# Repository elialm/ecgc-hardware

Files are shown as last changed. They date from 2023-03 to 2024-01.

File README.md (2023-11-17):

# ecgc-hardware

This repo contains all relevant documentation of the cartridge hardware.

The `legacy` directory contains legacy documentation.
This is just a collection of documents I made *waaaay* back when I was
just starting on the project.
It is included here just as an archive so I don't plan on updating anything.

The `CartGen3ProtoBoard` directory contains the schematics for the
first working prototype mentioned at [my website](https://efacdev.nl/posts/ecgc/20220601).
The photograph below is this prototype.

[gen3prototype-photo](https://user-images.githubusercontent.com/43206514/217519505-81669f43-df62-44b2-97f7-6338e39c4504.png)

The `CartGen4` directory contains the schematics for the
next prototype.
I've included some renders of it below.

[gen4-render-front](/CartGen4/img/front.png)  
[gen4-render-back](/CartGen4/img/back.png)

# Development tools

The tools used to make the schematics is [KiCad](https://www.kicad.org/).
It can be used to open the `*.kicad_pro` file to open the schematic
project.

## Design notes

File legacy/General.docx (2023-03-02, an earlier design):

# Gameboy flash cartridge

# Foreword

This document is a general overlook on the project. Here I explain mostly how my thought process went and which steps I took to get to where I am now. Additional references are provided to those who are interested in helping/making something cool which my sources (I’d love to see someone taking my work and expanding on it).

For a bit of context: I’m a HBO student (sort of University, but not quite) in the Netherlands studying ICT & Technology. During my study, I learned to program (C#, C and C++) and also learned how to work with microcontrollers and the like (among other things). I love working with low level stuff and am enthusiastic about learning about all kinds of different technologies.

During the Corona pandemic, I was looking for a way to fill my time. A year prior, I stumbled on the documentation for the GB. As I’m quite curious about older hardware and wanted to study more about the inner workings of computers/processors, I was quite interested in developing something for the GB. I didn’t really want to make a game (I’m not a game developer) and I didn’t have any other idea (or time) to use this information, so I quickly canned it.

After I bought a used GBC on ‘Marktplaats’ (basically eBay in the Netherlands), I was looking for ways to use it. I wanted to experience the hardware first-hand by playing some games on it and upgrade the thing to be a bit more modern (Li-ion battery mod and IPS screen mod), I saw a flashcard for it. As I was looking at it, I started to think about how that darn thing works, which led me to the path of trying to make one. I also had quite some free time during the pandemic, so that helped seal the deal.

# Description

The project goal, is to develop a flash cartridge for GB/GBC like the one in the picture below. The flash cartridge should be able to load games from a library on a common storage medium (best candidate is SD card) to play on the handheld. I want the cart to be compatible with GB and GBC (I may think about the GBS, but that is currently not the focus).

The project is separated into 3 parts: the cart hardware, the cart firmware and a selection menu software. I will need a game cart, capable of accommodating an SD card and additionally needed hardware (RTC and possibly more). I will also need some firmware to load the game, communicate with the SD card and probably some other stuff. And I will need a way for a user to select a game from the flash card for the cart to load.

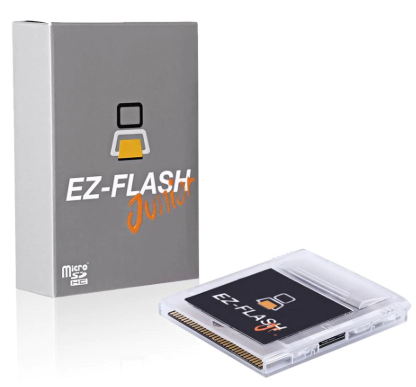
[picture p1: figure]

A picture of the EZ-FLASH GB flash card. Source: https://pt.aliexpress.com/item/4000718442858.html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

I currently have no real experience in developing hardware, so I will probably make a lot of mistakes in the electrical part (I’m a Software Engineer in training). My plan is to research the GB hardware to get an idea of what I need, then make a prototype cart, in order to test some firmware on it and get a better idea of what I need. Then, I’ll basically repeat this procedure, till I get the result I want.

# Requirements

As stated in Description, the ultimate goal is to create a cart that can load games from an SD card. For development, I need to break the project down into smaller parts.

## User requirements

1. As a user, I must be able to select a GB game file on the SD card, in order for me to play it. This is the basic requirement I need the cart to do. When a user insert the cart and boots the handheld, it should boot to a game selection menu of sorts, where a user can select his/her game.  In order to do this, I will need to be able to communicate with the cart to firstly get the game list, then by the user’s selection, load said game into some sort of buffer, as the GB can’t read directly from the SD card (refer to Research document ‘Bus decoding’ as to why). While the cart is responsible for loading games, I will also need a user interface to run on the GB. This will be the first thing that the GB loads when booting from the cart.
2. As a developer, I want to be able to write my own firmware versions, in order to add functionality to the cart As I’m a curious soul and want to spread that to the masses, I want to share the knowledge acquired from the project and document everything important for other people to develop their own firmware version (or maybe their own cart).  I will share documentation and other files regarding the development of this cart and publish it somewhere on the internet.
3. As a user, I want to be able to relatively easy change the look of the user interface, in order to customise my experience I like to customise my menu’s (be it my desktop, phone or 3DS). I want to add the functionality to change the look of the game selection menu (fonts, splash screen, BGM, you name it).  It’s a lower priority, but I will try to make a desktop program to make a ‘theme’ file, which you can put on the SD card to change the look of the UI.
4. As a user, I want to be able to create backups of my save files, in order not to lose progress. As someone who enjoys games, I despise it when I lose my saves. Now it’s becoming harder to lose said saves, with cloud storage and all (thank god), so I want to take that modern approach and use it on my platform.  It will probably take quite some work and it’s not really important, but it would be nice to have some kind of service that the cart can connect to, in order to backup saves (some kind of OneDrive). It would be cool if the cart has Wi-Fi hardware, so that it could communicate with such a service.
5. As a user, I want to be able to play multiplayer games that I would normally play using the Link interface or IR interface, but then over Wi-Fi, in order to play with people all over the world. Quite ambitious, but it is a cool idea. If I could figure out how to hijack the Link or IR interfaces, I could reroute the data from those interfaces through a network socket. Theoretically, one could then connect with users al over the globe and play multiplayer.  As this a HUGE requirement, it will receive a low priority. In order to do this, I would probably make some kind of service that clients can use to connect to one another. Same as the backup requirement, it takes a lot of time and effort to create such a think and it’s something to do, when the cart itself doesn’t have anything else going on.

## Functional requirements

Based on the user requirements and some research, I formulated these requirements. These requirements describe the more detailed requirements on a system level, needed to fulfil the user requirements.

1. The GB and cart must be able to communicate with each other To instigate certain behaviours in and to pass data to both the GB and cart (think about the cart telling the GB which games are available or the GB telling the cart which game it has selected), the GB and cart will need to be able to communicate with each other.  As the interface in between the GB and cart is the address and data lines, the cart will need to use a bit of the address space as a communication medium. I will probably use a bit of the cart RAM, but I will think about it when the time comes.
2. The cart needs to communicate with the SD card To read games and save data to non-volatile storage, the cart will need to communicate with the SD card.  Communicating with an SD card goes over an SPI connection. The cart will then need SPI functionality. For the software part, I will probably use some open source library. Writing it myself seems unnecessary. Although, it might be a fun learning experience.
3. The cart will need some ‘brains’ to execute certain commands To do stuff like communicate with the SD card and GB, read and write data, the cart is going to need some central processing. Also for me to customise the behaviour of the cart and because it needs to do some complex stuff, it seems wise to do this software based.  I will probably slap a microcontroller on the cart to do these things. Additionally, the research till now, suggests I will need some hardware acceleration, so an FPGA might also be handy. I’ve never used one before, but I’ve been wanting to learn to develop for an FPGA, so again, an excuse to do something new! I currently looking into something called PSoC.
4. The cart will need a memory buffer to act as cart ROM and RAM The GB uses a parallel 16-bit address and 8-bit data bus to communicate with what normally is the ROM (and RAM) on the cart. As the speed with which the GB reads from and writes to the cart is quite fast, it would be wise to have a buffer in between the data on the SD card and the GB. This would ensure both speed and minimise wear on the flash medium.  I will probably use some RAM chips to act as the memory buffer. It’s fast, reliable and resistant to the wear and tear from every game load.
5. The cart will need an RTC unit Some games on the GB use an RTC. This is a piece of hardware, which can keep track of the date and time. This is also a convenient thing to have, for the purpose of displaying time.  The easiest thing to have, is a MCU that has an integrated RTC. This is a common thing, so it shouldn’t be hard to find one.

## Non-functional requirements

1. Cart should use least power possible Because the GB is known for being low power, I want my cartridge to use the least amount of power possible. Use of the cartridge shouldn’t drain 2 AA batteries in an abnormal way.  This should be achieved by carefully writing the cart firmware and disabling any peripherals not needed at the moment. I could also choose low power chips inside the cart.

# General idea

Here I describe the general idea of how I want to design my system. This includes all parts of my system and how they communicate/interact with each other. This will be quite rough, but should serve as a strong base to build upon.

## Cartridge hardware

The cart can be separated into 3 main parts: the Bus decoder, the memory and the MCU (Microcontroller). See below for an image visualising the connections between the parts.

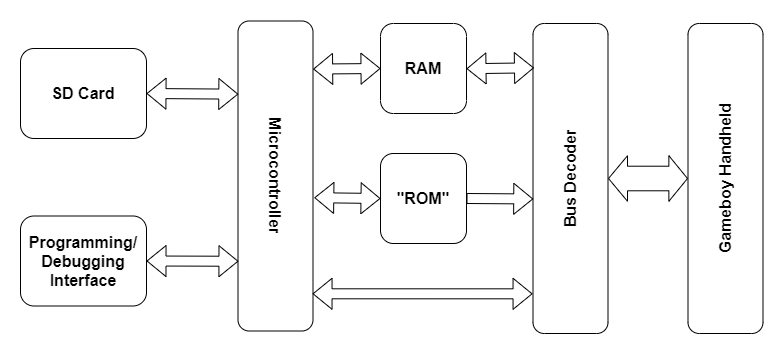
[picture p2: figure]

Diagram showing the different parts of the cartridge and how they can interact.

The Bus decoder is the part which communicates with the GB. Its job is to decode the read/write requests from the GB and execute them. For a more detailed explanation about the decoder, see TODO: Write detailed explanation about decoder

The memory is where the game code and data reside. This is made out of 2 parts: the “ROM”, which is the part of the RAM that acts as ROM; and the RAM, which is also RAM and can be used by the GB as cart RAM. For a more detailed explanation about the memory, see TODO: Write detailed explanation about memory

And finally, the MCU. This part runs the firmware code and is responsible for the more complex behaviour of the cart. This part also communicates with the SD card, for loading in game code and data. For a more detailed explanation about the MCU, see TODO: Write detailed explanation about MCU

## Cartridge firmware

The firmware is the code running on the MCU which resides on the cart. To facilitate the execution of certain behaviours, it seemed wise to have a MCU with updateable firmware. The original plan is to have a MCU with a bootloader, which reads a firmware file on the SD card and executes this firmware.

The general stuff the firmware does is as follows:

- When starting up, read and download the firmware file on the SD card (done by the bootloader)
- Upload the menu program for the GB into the cart memory
- Configure the decoder for use with menu program
- Enter in a mode, which waits for requests from the GB (e.g. load selected game, get or set the date/time)
- When a game has been selected, upload selected game (and optionally save data) into the cart memory
- Configure decoder for use with selected game
- Enter power saving mode, if MCU is not needed anymore
- When GB powers off, save the RAM to a file on the SD card

For a more detailed explanation about how the firmware works, refer to the code. I’ve written enough comments to adequality explain the inner workings.

TODO: Write the damn code

## GB User Interface

# Cartridge Iterations

This chapter is to show the different iterations I’ve made of the cartridge and to discuss how they works, why I did certain things and what I would change about them in the next iteration.

## Model PT - Prototype Test

This is the first prototype made for this project. As I’ve wanted to experiment with the memory, I’ve let out the MCU out of this design. I don’t have any experience in designing a board for a MCU and I didn’t want to have complications because of that. Also, I haven’t decided on the MCU that will run the show and I wanted to do this after I have a better picture about using the memory. This iteration also doesn’t have an SD card reader for the same reason. MCU and SD card reader should be added externally.

### Hardware

This design contains 2 RAM chips: a 64Mbit and a 1Mbit chip. The 64Mbit is to be used as the “ROM” section of memory and the 1Mbit chip as the RAM section. Both chips are connected to the address bus coming from the GB to access their part of the memory map (see research document for an explanation why TODO: Write said explanation). Because the chips are much bigger then their allocated part in the memory map, they have a couple extra address lines to address the banked memory. The extra lines are connected to jumper pins, which can be connected to a MCU for the higher addresses (See picture below for diagram showing the address pins wiring). When the GB then wants to access different banks, the higher bits should then be set by the MCU, in order to access these banks.

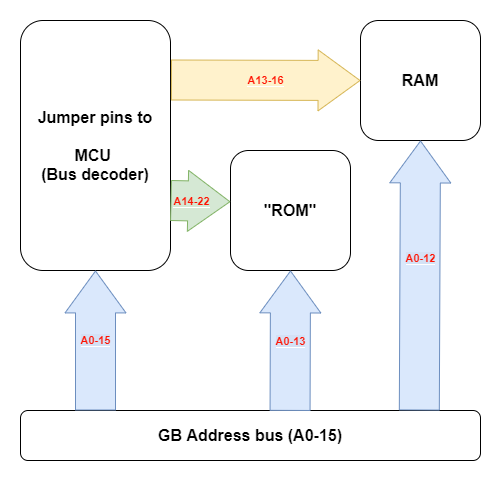
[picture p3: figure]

Image showing wiring of address lines.

Additionally, the data bus of both chips are also connected to each other and to the GB data bus (See image below for wiring diagram). As these lines can be driven by the RAM chips, care should be taken that they don’t try to use the data bus at the same time. This can be achieved by using the ‘Output Enable’ and ‘Chip Enable/Select’ pins of each chip (accessible via the jumper pins). Still, read their datasheets for a more detailed explanation of their inner workings.

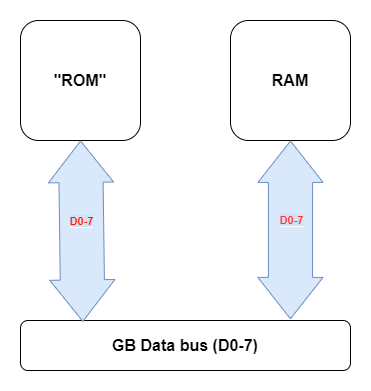
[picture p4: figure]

Image showing wiring for data bus.

I couldn’t find RAM chips of adequate size that work on 5V, So I’ve had to settle on chips that work on 3.3V. Because of this, I needed some components as voltage translators. The most notable are the bus transceivers, which are mainly used as down translators that translate the 5V logic signals coming from the GB to 3.3V signals (address bus, data bus and control signals). They have another function, which is to isolate the GB when the MCU wants to access the RAM chips. During some operations (e.g. when loading in the selected game) the GB shouldn’t be able to access the cart memory, so the bus transceiver can be used to block the GB’s signals. This can be achieved manipulating the control pins of the bus transceivers (see their respected datasheet for how they operate).

Because of the fact the RAM works with 3.3V logic, I’ve made the decision to use only 3.3V logic on the cartridge. This should simplify communication between components on the chip (I don’t have to constantly translate voltages). The only isolation still needed by the cart, is the RESET line. This is a line the cart can pull down to reset the GB. As this is also 5V logic, I’ve isolated it from the rest of the cart, using a level shifter. The level shifter can be used to pull the RESET line down.

To use the cart, I’ve exposed some connections by using jumper pins. These connect to nets, which I’ve seen as useful to have access to. These pins should then be connected to a microcontroller. WARNING: All pins connect to 3.3V logic. You should NOT put 5V on these lines. Doing so will most probably damage components on the board. There are 3 sets of 8 pins. The unlabelled pins are connected to ground. For description on the labelled pins, please refer to the next table.

Pin(s) | Name | Description
DIR | Direction | Change the input/output direction of data transceiver.
OE | Output Enable | Enable the output of data on the 1Mbit RAM chip.
CS | Chip Select | Enable 1Mbit RAM chip.
WE | Write Enable | Specify a read or write operation on the 1Mbit RAM chip.
A13-16 | Address lines | Higher address lines of the 1Mbit RAM chip.
RST | Reset | GB reset line (connected through level shifter). Pull down to reset GB.
CS | Chip Select | GB chip select line (down-translated to 3.3V). Active LOW. When active, GB is communicating with cart.
RD | Read | GB read line (down-translated to 3.3V). Active HIGH (HIGH means read). Is opposite from WR line.
WR | Write | GB write line (down-translated to 3.3V). Active LOW (LOW means write). Is opposite from RD line.
CLK | Clock | GB clock line (down-translated to 3.3V). Used to time read/write operations.
OE | Output Enable | Enable the output of data on the 64Mbit RAM chip. Pull high to tristate the output (for manipulating address lines via MCU).
CE | Chip Enable | Enable 64Mbit RAM chip.
WE | Write Enable | Specify a read or write operation on the 64Mbit RAM chip.
A22-14 | Address lines | Higher address lines of the 64Mbit RAM chip.
A15-0 | Address lines | GB address lines (down-translated to 3.3V)

Some of the pins on the chip have either been pulled high or low, because they weren’t needed to be changed during operation. To identify these pins and see where they are tied to, please refer to the schematics. For more details about how to use these chips, please refer to their respected datasheets. To identify the pins, please refer to the silk screen on the board (or see picture below).

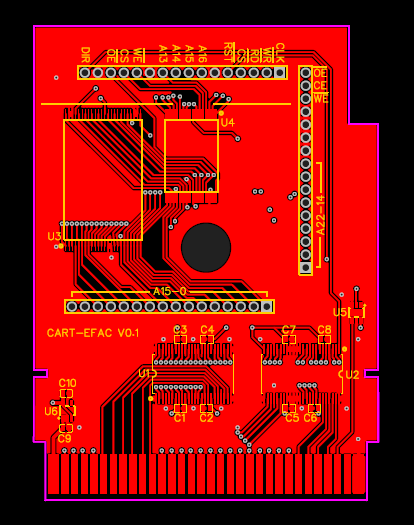
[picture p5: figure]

Image of top of board design, on which the silk screen can be visible.

For more details on wiring, see schematics and/or board design.

### Fixes for next iteration

This board has a lot of faults. The faults are so big and numerous in fact, that I haven’t used this iteration for any testing. When I was inspecting the boards after I’d ordered them my big glowing brain started working again and I found a lot of things wrong with it (like missing pins and wrong connections). Nothing wrong with the company who made the board or the manufacture of the board, just design faults I made (to make things clear). Here’s a list of faults with the board to fix with the next iteration:

RST Buffer doesn’t block 5V
When I designed the board, I wanted to be able to reset the GB via the RESET line. Because this is connected to the GB, it is 5V logic. To protect the MCU running on 3.3V, I put a buffer on the board connected to the RESET line (see U5). I thought this would block the 5V of the pin, but when not connecting the input of the buffer, the input sits at around 5V. When driving the pin to 3.3V (which would mean that the GB shouldn’t reset), it drops down to about 4V.

As this is not ideal, I’ve decided to remove the buffer and replace it with a voltage divider circuit. If I use a 10k and 20k resistor, I should be able to lower the RESET line voltage going to a GPIO pin on the MCU, whilst being able to pull this line down via the resistor (and resetting the GB).

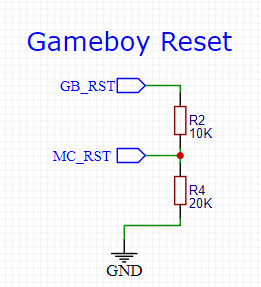
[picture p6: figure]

Image showing current setup for the reset pin

Linear power supply not enabled
I put a linear power supply on the board, in order to power the 3.3V components on the board from the 5V power supply coming from the GB. The chip I chose, had a enable pin, which was active high (the power supply is enabled when connected to HIGH). Because I apparently only had one braincell working, I connected it to the output of the supply. Because of this, you have a classic chicken and egg problem, where the enable line must go HIGH, but to do that, the supply must be enabled. Just wonderful…

The solution is simple, just connect the enable pin to a voltage divider. If I use a 10k and 20k resistor connected to 5V (GB power rail), the supply should drop to about 3V, which the enable pin sees as HIGH (according to the datasheet, it sees voltages higher than 1.2V as HIGH).

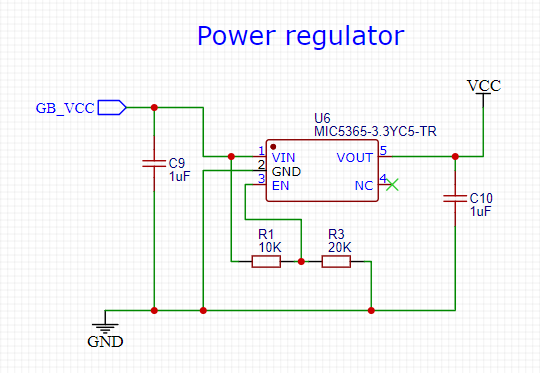
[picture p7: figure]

Image showing current setup for Linear power supply.

Some dimensions are wrong
To get the dimensions of a board that could fit inside a cartridge, I using an empty plastic cartridge and the board inside it. I must have measured things almost perfectly, because the board was a tad to big (like maybe 0.2 bigger in most dimensions). Because of this, I had to sand some sides down to get it to fit.

Also, the thickness of the board it to large. When I tried to put the board inside the plastic casing, the lid wouldn’t close. I eventually got it closed, but then the card wouldn’t slide completely inside the cart slot. The board is to thicc to fit inside the cart slot.

And finally, the hole is a bit higher then it should be. Luckily, the hole was big enough to still fit, but this is not ideal.

I’ll give the next iteration some clearance, so that I don’t have to sand it again (not that it’s terrible, but since I’m making a new one anyway, I might as well change it). And more importantly, I next need to order a thinner PCB. I measured with a random board it to be 0.8 mm. Also, I need to change the size and position of the hole to fit nicely.

Data bus not accessible via pin to MCU
Quite an embarrassing thing to forget, but I forgot to add pins to connect the data bus coming from the bus transceiver to the MCU. Because of this, the MCU can’t put data on the bus to write to memory, meaning it can’t load the game.

As this is pretty important, this should be fixed in the next iteration. I’ll next add some extra pins, which are connected to the data bus.

## Model PM - Prototype Modular

For the next iteration, I wanted to make a drastic change. When buying the parts for the last iteration, I accidentally bought the wrong 64Mbit chips. I originally ordered it from another supplier, because the SRAM chip costs about €26 on Mouser and I found another for about €2,50. The price difference should’ve been obvious, but I don’t think I had slept well that night. So now I have 256kbit chips laying around for other projects.

Because I don’t want to ‘waste’ a €26 chip on every iteration, I decided to make the next iteration modular. I made this one with the possibility to connect 2 daughter boards: one for memory and one for the MCU. This way I can reuse this iteration and when I want to add the MCU, I can just make a daughter board for it. For now, I’ll just make a daughter board with pins to connect to an external MCU (for testing purposes) and a daughter board for the memory (“ROM” and RAM).

### Hardware

Firstly, let’s go over some changes compared to the last iteration:

As stated in the introduction, I’ve made the change to be able to add daughterboards. I’ve opted for a 40 (2 x 20) pin interface with the memory board and a 50 (24 + 26) pin interface with the MCU board. I chose to use 2 connectors to distribute the pins better and to have a more stable physical connection.

The wiring of the address bus is slightly different. In the last iteration, I wired the address buss coming from the GB directly to both memory chips, while 2 separate busses for the higher addresses exist. Because the bus can either be used to communicate with the “ROM” chip or with the RAM chip, I’ve combined these 2 busses. Now, the bus is hilariously named the “Bank bus” used to select the wanted bank in memory. This saved me 4 pins, so quite nice. See diagram below for a visual representation. The control pins have also been changed, combining the WE (write enable) and OE (output enable) pins with separate chip select pins to select either chip, because again only one chip can be used at a time. Warning: be sure to select only 1 chip at any time. Not doing so may damage them.

TODO: Add address diagram

This iteration has the possibility to add a retainer for a coin cell battery. The battery can then be used for stuff like RTC time keeping and retaining data. The retainer I chose can hold 1220 and 1225 series batteries. I also included a charger circuit for the use of rechargeable batteries. This circuit can also be left out by not soldering the components, but instead shorting R5. I meant for the rail to be powered by 3V, however as the battery power pin is a separate pin going to both of the daughter boards, you could put any voltage on it (as long as the connected hardware support it).

Control over the transceivers has also been improved. This time I thought more about how both the GB and MCU use the parallel address and data bus and changed the operation of the transceivers in a way that this goal can be achieved.

The address transceiver only needs to pass data from the GB to the cart address bus (connected to MBC/MCU and RAM chips), so the DIR pin is still tied to ground. The transceiver has an additional pin that controls the pin state (when low, one bus is input and other output and when high, both busses are tri-stated). Originally I had this also tied to ground, but it’s something very handy for the MCU to control, so I connected this pin to the MCU interface (also for the data transceiver).

This enables the MCU to block signals coming from the GB and communicate with the RAM chips. This is useful, for example, if you want the MCU to run code on its own and use part of the RAM, creating shared RAM. When the GB is then not using the bus (in between read/writes) the MCU can use it to, for example, output data when being used as a co-processor of sorts. This level of control is then necessary, because when the GB is not communicating with the cart, it still pollutes the address and data bus.

Care should be taken when doing this, because the GB obviously loads instructions via the cart, so it uses this bus a lot. Luckily, it seems the communication is so slow (GB_CLK works at 2MHz) that it should be possible to preform reads and writes in between the requests from the GB. The GB takes 480 ns preparing for the read/write and then an additional 480 ns to preform it. As the access time for both RAM chips is only 55 ns, you could (theoretically) preform 3 additional write/read requests when the GB is doing it’s thing.

TODO: More research/prototyping in necessary for exact workings, but it should be possible.

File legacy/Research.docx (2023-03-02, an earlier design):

# Gameboy flash cartridge

# Foreword

This document is meant as a place for me to note any research made for myself and others. It is meant as ‘proof’ for the concepts I’ve learned about during the making of this project and as a guide for other people to better understand the choices I’ve while making this project.

# Hardware modifications

## Battery mod

As I’ve stated in my General document, I bought a GBC as a way to play older games on older hardware. One thing I hate about the GBC, is the fact that the thing uses AA batteries. That’s why, I want to modify the hardware by adding a rechargeable battery. This should allow me to use the GB more comfortably and longer.

I mainly got the information I needed from a YouTube video (https://www.youtube.com/watch?v=tGUx15ZgTeQ). This is where I got the information to use a rechargeable Li-ion battery and a Li-ion battery charger circuit.

As I had these laying around at home, I didn’t have to buy them. However, I was scared about the voltages used. The battery itself usually sits around 3.7V (as Li-ion batteries normally do) and the charging voltage is 4.2V. The GB normally uses 2 AA batteries, which connected in series have a maximum voltage of around 3V. Because of the way the battery and charger are connected (see picture below) it puts the charging voltage on the pins that normally only take those 3V.

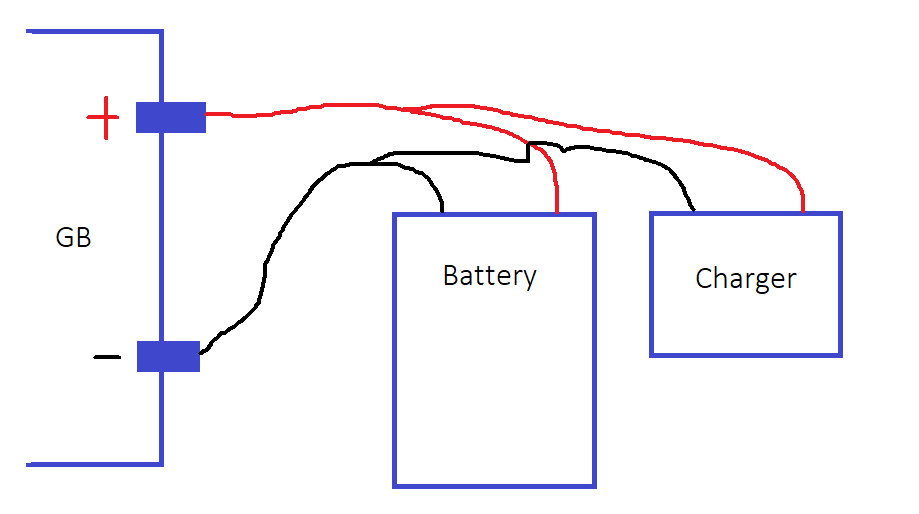
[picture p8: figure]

Image depicting battery and charger connections to GB.

I didn’t know it that was a problem, so I took it to the internet. From this (https://blog.gg8.se/wordpress/2009/07/22/testing-gameboy-input-voltage-ranges/) source, I got the battery and charger voltages are within normal range and I basically wouldn’t have any trouble with the charging voltage. The article spoke about having connected the GB with 9V for an extended period of time without any hiccups, so I trust it won’t be a problem to connect 4.2V. I’ve connected by GBC to a power supply of 4.2V without any trouble as well.

TODO: Connect GB for a long time with battery circuit

TODO: Connecting LED battery indicator

TODO: Give some metrics (charge time, discharging time)

## Screen mod

A great mod I saw in a video, was a screen mod. In it, the original screen is replaced with a modern backlit screen. The original GBC screen has no backlight illuminating the screen. Because of this, the GBC has a better battery life, but sacrifices visibility. A user must hold the GBC by a light in EXACLTY the right angle in order to maximize brightness, whilst minimizing glare.

As this is quite annoying and because I want to be able to game in a dark room, I chose to order this (https://www.aliexpress.com/item/4000338739866.html?spm=a2g0s.9042311.0.0.7b6c4c4dyz4Ypk). It is a GBC compatible backlit screen with included case. Because of the battery mod, you need to modify the case and I didn’t want to ruin the original casing (and I was missing the battery door). There is a version without case, if you’re interested.

Instructions aren’t really given to install the screen, so here’s what I did:

- Connect screen to check orientation and if it works or not (very important)
- Fit screen inside the case and test monitor. As the screen is a bit smaller, it needs to be fitted using sticky foam. Be careful that the borders don’t overlap with the screen and that the screen is parallel with the case.
- When happy with screen placement, you can close the GBC. The screen has a capacitive button, that you need to place in front of the IR LED’s. Using this button, one can change the brightness of the screen. The board probably has some pins you can connect to the buttons, if you don’t want to sacrifice the IR interface (haven’t looked into this, as I don’t care about the IR LED’s, might change it in the future).

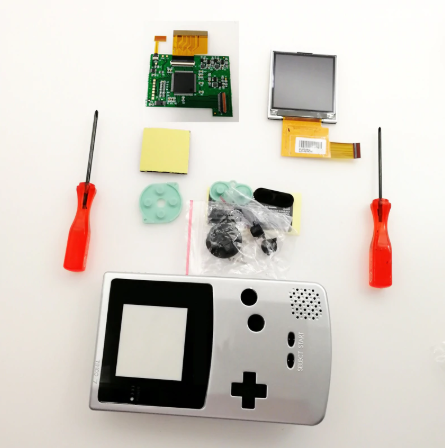
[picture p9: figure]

Image of screen mod part. Taken from https://pt.aliexpress.com/item/4000338739866.html?spm=a2g0s.9042311.0.0.7b6c4c4dyz4Ypk

# Cartridge Hardware

## General workings

At first, I need an general concept how a flash cart could work. To get a general idea, I took to the internet to get inspiration. A simple cartridge has a ROM (Read Only Memory) chip and some circuitry. The game’s code and data is saved on the ROM chip. When the GB tries to read data from the ROM, there’s usually some logic that decodes the signals from the GB, that in turn retrieve the data from the ROM and passes it to the GB. This is called a MBC, or Memory Bank Controller.

A cart can also contain additional RAM. This RAM is usually battery backed, which means the RAM retains data after the GB has been powered down. This is very useful for save data, as the GB can read and write to this memory. And again, there’s usually some logic between the GB and physical memory.

I lost where I got the information from, but when you look at the different links on the Gameboy Dev site (https://github.com/gbdev/awesome-gbdev), you can piece it together.

In a traditional flash cart, the games and saves are stored on an SD card, but are not accessed directly by the GB in that way. As I’ve discussed in my research in the ‘Bus decoding’ part, the GB can’t access the SD card directly and needs an intermediate. That’s where I got the idea of using RAM memory as a memory buffer for the ROM and RAM that would normally go on a cart. The RAM can be used to replace the ROM, as they work similarly. I also need to frequently change the contents of the “ROM” (every time when a new game is loaded), so using RAM is pretty advantageous, as it can withstand a lot or reads/writes.

It would also be wise to have a firmware based MBC. This would enable me to implement the different MBC in firmware, rather then have it be hardware. I’ve looked on the internet and stumbled upon things called FPGA’s. These are devices with programmable logic units that can preform basic operations. These blocks can be chained together, in order to preform a multitude of operations. It’s basically hardware you can program. Because reprogramming the FPGA probably needs a dedicated programmer, it probably won’t be possible to change the firmware by and end user (without experience in the field), but that’s a compromise I’ll have to make.

I think that the best approach, would be to combine an FPGA with a MCU (Microcontroller Unit). The FPGA would then be used to act as the MBC and communication point for the GB, whilst the MCU would do more complex stuff (communicating with SD card, loading games, etc). Using a MCU also enables me to base the system on firmware, which would make the system very flexible. The firmware can then be loaded from the SD card, enabling the option to easily update firmware (also by end user). The FPGA probably can’t be changed on the fly, so I should give it a lot of options, in order to increase flexibility (options like direct communication with MCU, selection of MBC, etc).

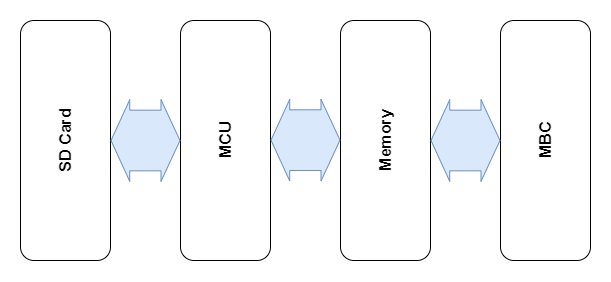
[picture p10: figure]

Diagram depicting general parts and interactions between components.

## Bus decoding

The GB communicates with the cart via a 32-pin parallel interface. This interface is made up of these components:

- CLK, which gives the timing for a read/write
- RD, which signals that the GB is trying to read from the cart
- WR, which signals that the GB is trying to write to the cart
- CS, which signals that the GB wants to communicate with the cart
- A0-15, a 16-bit address bus, used to signal which address the GB is trying to read from or write to.
- D0-7, an 8-bit data line, used to send or receive the data written to or read from.
- Reset, used by the cart to reset the GB

The way the communication works, is by specifying at what address a read or write should be performed with the given data.

For example, a read is done by putting the address from which you want to read on the address bus and specifying a read operation with the control signals (RD, WR, CLK & CS). Then the cart will output the data on the data bus, which the GB can read from.

A write is done in a similar manner. The GB puts the address it wants to write to in the address bus and specifies a write operation using the control signals, while outputting the data to be written onto the data bus.

Using these operations, the GB can effectively communicate with the cart, by reading from and writing to it. When making the hardware for the cartridge, we need to decode the signals being sent to the cart and handle the requested operation.

I’ve looked at this (https://dhole.github.io/post/gameboy_cartridge_emu_1/) article, where a person by the name of ‘Dhole’ used a STM32F4 board to emulate a cart. In that project, Dhole used a digital analyser to analyse the cart port and deduce what the different signals meant. Since I don’t have a digital analyser, I used this as a reference of which signals I’ll need to manipulate. Below is an image and graph for more clarity.

TODO: Try communicating with GB with prototype board

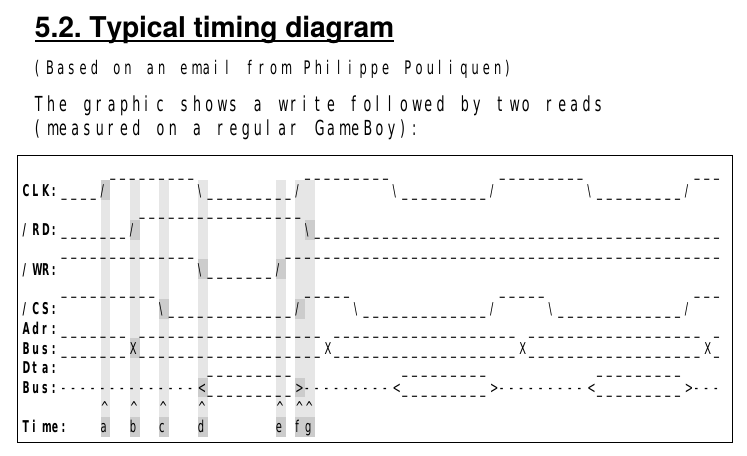
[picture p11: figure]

Image showing signal timing diagram. Source: http://marc.rawer.de/Gameboy/Docs/GBCPUman.pdf

Operation | RD | WR | CS | Address Bus | Data Bus
Read | L | H | L | X | X
Write | H | L | L | X | X
Ignored | X | X | H | X | X

Truth table for control signals. Made by analysing article by ‘Dhole’

TODO: Test truth table

# Cartridge firmware

## Using FreeRTOS

## SD card communication

As per the user requirements, I want to use an SD card to save games and additional data. To use the SD card, I need a communication peripheral and some firmware to go along with it. This includes:

- Low level communication (sending raw bytes)
- SD card communication protocol
- Handling the filesystem

My original plan was to make this from scratch, as I wanted to have full control over the firmware and I didn’t want to deal with errors due to improper synchronisation with other tasks (see Using FreeRTOS).

I started with implementing some SPI functions to use with the SD card. The SD normally has 2 communication modes: SD mode and SPI mode. SPI mode is very useful in our application, because SPI hardware is very common for MCU to have. If you’re not acquainted with SPI, I highly recommend this (https://www.youtube.com/watch?v=fvOAbDMzoks) video by ‘GreatScott’ explaining it.

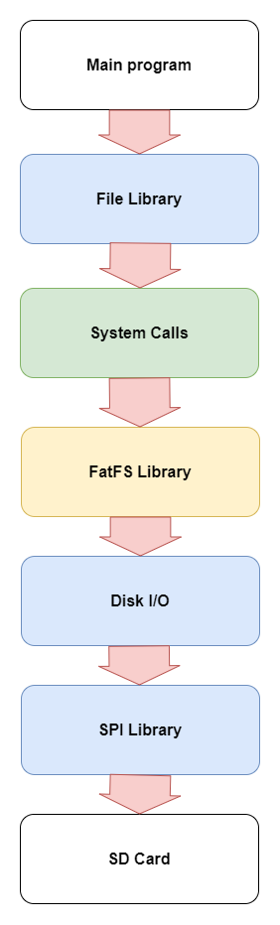
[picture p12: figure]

I found 2 very helpful articles, explaining how SD card work with SPI which I mainly used for my implementation. You can find these articles here (http://www.dejazzer.com/ee379/lecture_notes/lec12_sd_card.pdf) and here (http://elm-chan.org/docs/mmc/mmc_e.html) (first one written for the Electrical Engineering Department of University Buffalo, the second one written by a user named ‘CHaN’). Anyhow, I used these sources to write an SPI driver and I started making an SD communication library. However, things were taking quite long and when I looked at what I still had to do, I started to look for libraries.

I used a library in the past called ‘FatLib’ by GitHub user ‘gallegojm’, which is a FAT-FS library to use on an Arduino to communicate with an SD card (repository can be found here (https://github.com/gallegojm/Arduino-FatLib)). It’s a nice library with a lot of different functionalities. When I was looking how to port it though, I found out that the program I was using to program my prototype board (PSoC Creator) didn’t support C++, so that plan went out the window. I did find out that FatLib library used a different library to handle all FS logic, the ‘FatFs’ library written by ‘CHaN’.

When I was looking for information, I stumbled upon an article by Balau, explaining how to access the SD card using SPI on the STM32 Nucleo. Here he explains that usually when implementing FS, there is a layered model to go by (see image left). The idea is to separate all the logic that goes into using an SD card, into layers that can be interchanged. If I follow this layered model, I won’t have to write FS logic (yellow). I’ll only need to write the things in blue and design an interface for the OS to handle file requests (green).

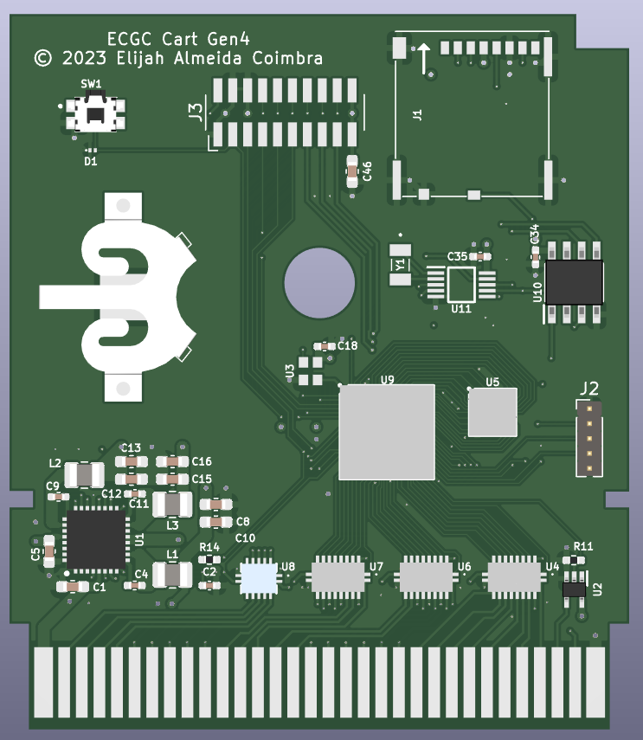
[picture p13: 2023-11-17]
CartGen4/img/front.png

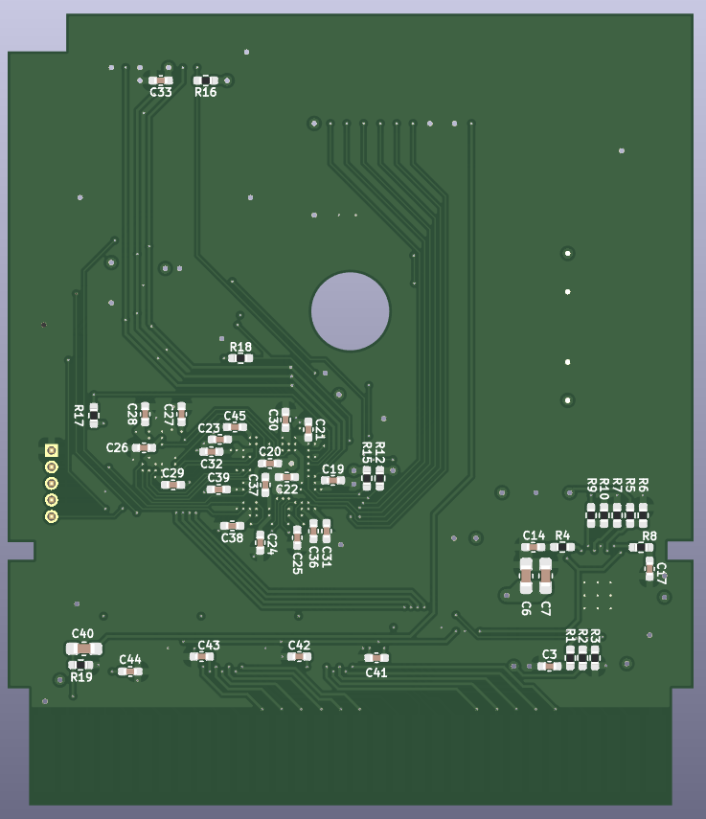
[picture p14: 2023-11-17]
CartGen4/img/back.png

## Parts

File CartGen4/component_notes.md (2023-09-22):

# Notes about component selection

This document describes the considerations needed with some components.
Not everything can be described perfectly on the schematics
without cluttering the entire thing.

## Considerations around TPS65266-1

### Introduction

The [TPS65266-1](https://www.ti.com/product/TPS65266-1) is a Switched Mode Power Supply (SMPS).
The TPS65266-1 incorporates 3 channels of high-efficiency synchronous buck converter for applications operating off the adaptor or battery with input voltage lower than 6 V.
It is used here to generate 1.2V, 1.8V and 3.3V for the different components.

### LX inductors (L1, L2 and L3)

**TODO: write**

lx inductor: MAKK2520H100M 10uH
	- calculated value
	- max DC current 500mA
lx capacitor: CL21A226MQQNNNF 22uF
	- calculated value
	- Resr must be within range
vin capacitor: CL10A106KQ8NNNC 10uF
	- 10uF recommended
	- high-quality ceramic type (X5R or X7R)
Rc resistor:
	- calculated value
Cc capacitor:
	- calculated value
Sense resistors:
	- used values from table
	- tolerance <1% recommended
Css capacitor:
	- consider downstream specific timings
	- FPGA has no requirements
Bootstrap capacitor:
	- 47nF recommended
	- voltage rating of 10V or higher
Pgood pullup resistor:
	- between 10k and 100k recommended
Rosc:
	- calculated value
	- fsw = 100MHz

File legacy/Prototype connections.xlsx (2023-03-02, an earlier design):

MACH pin | DRAM pin | A Transceiver | D Transceiver | Description | IO Bank | Extra functionality | Extra description | Candidate
A3 | 26 |  |  | A3 | 0
A4 | 25 |  |  | A2 | 0
A5 | 24 |  |  | A1 | 0
B7 | 23 |  |  | A0 | 0
B9 | 22 |  |  | A10 | 0
F7 | 21 |  |  | BA1 | 0
C4 | 20 |  |  | BA0 | 0
D6 | 19 |  |  | CS# | 0
C7 | 18 |  |  | RAS# | 0
D8 | 17 |  |  | CAS# | 0
E9 | 16 |  |  | WE# | 0
C10 | 11 |  |  | DQ3 | 0 | JTAGENB
D10 | 8 |  |  | DQ2 | 0
E11 | 5 |  |  | DQ1 | 0
B12 | 2 |  |  | DQ0 | 0
C13 |  |  |  |  | 0 | DONE
A13 | 53 |  |  | DQ7 | 0 | INITN
F8 | 50 |  |  | DQ6 | 0
C12 | 47 |  |  | DQ5 | 0
E10 | 44 |  |  | DQ4 | 0
F9 | 39 |  |  | DQM | 0
E8 | 38 |  |  | CLK | 0
E7 | 37 |  |  | CKE | 0
D7 | 36 |  |  | A12 | 0
C5 | 35 |  |  | A11 | 0
E6 | 34 |  |  | A9 | 0
A10 | 33 |  |  | A8 | 0
D9 | 32 |  |  | A7 | 0
B6 | 31 |  |  | A6 | 0
B5 | 30 |  |  | A5 | 0
B4 | 29 |  |  | A4 | 0
 |  | 24 |  | 2DIR | 1
B16 |  | 23 |  | 2B8 | 1 |  | GB_ADRR[15]
F14 |  | 22 |  | 2B7 | 1 |  | GB_ADRR[14]
E14 |  |  |  |  | 1 | R_GPLLC_IN
E15 |  |  |  |  | 1 | R_GPLLC_FB
D14 |  |  |  |  | 1 | R_GPLLT_FB
D16 |  |  |  |  | 1 | R_GPLLT_IN
C15 |  | 20 |  | 2B6 | 1 |  | GB_ADRR[13]
E16 |  | 19 |  | 2B5 | 1 |  | GB_ADRR[12]
F16 |  | 17 |  | 2B4 | 1 |  | GB_ADRR[11]
F15 |  | 16 |  | 2B3 | 1 |  | GB_ADRR[10]
G15 |  | 14 |  | 2B2 | 1 |  | GB_ADRR[9]
H15 |  | 13 |  | 2B1 | 1 |  | GB_ADRR[8]
J15 |  | 12 |  | 1B8 | 1 |  | GB_ADRR[7]
J14 |  | 11 |  | 1B7 | 1 |  | GB_ADRR[6]
K16 |  | 9 |  | 1B6 | 1 |  | GB_ADRR[5]
L16 |  | 8 |  | 1B5 | 1 |  | GB_ADRR[4]
M16 |  | 6 |  | 1B4 | 1 |  | GB_ADRR[3]
N16 |  | 5 |  | 1B3 | 1 |  | GB_ADRR[2]
N14 |  | 3 |  | 1B2 | 1 |  | GB_ADRR[1]
K13 |  | 2 |  | 1B1 | 1 |  | GB_ADRR[0]
G14 |  | 25 |  | 2OE | 1 |  | BTA_OEN
 |  | 48 |  | 1OE | 1 |  | Connected to G14
G16 |  |  | 24 | 2DIR | 1 |  | BTD_DIR
H16 |  |  |  |  | 1 | PCLKC1_0
J16 |  |  | 23 | 2B8 | 1 |  | GB_DATA[7]
H14 |  |  | 3 | 1B2 | 1 | PCLKT1_0 | GB_CLK
K15 |  |  | 22 | 2B7 | 1 |  | GB_DATA[6]
K14 |  |  | 20 | 2B6 | 1 |  | GB_DATA[5]
L15 |  |  | 19 | 2B5 | 1 |  | GB_DATA[4]
M15 |  |  | 17 | 2B4 | 1 |  | GB_DATA[3]
L14 |  |  | 16 | 2B3 | 1 |  | GB_DATA[2]
M14 |  |  | 14 | 2B2 | 1 |  | GB_DATA[1]
K12 |  |  | 13 | 2B1 | 1 |  | GB_DATA[0]
T14 |  |  | 25 | 2OE | 2 |  | BTD_OEN
T12 |  |  | 5 | 1B3 | 2 |  | GB_CSN
R13 |  |  | 6 | 1B4 | 2 |  | GB_RDN
R11 |  |  |  |  | 2 |  | USER_RST

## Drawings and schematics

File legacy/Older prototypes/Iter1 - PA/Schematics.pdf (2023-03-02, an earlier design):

# ROM Pins

# RAM + Gameboy Control Pins

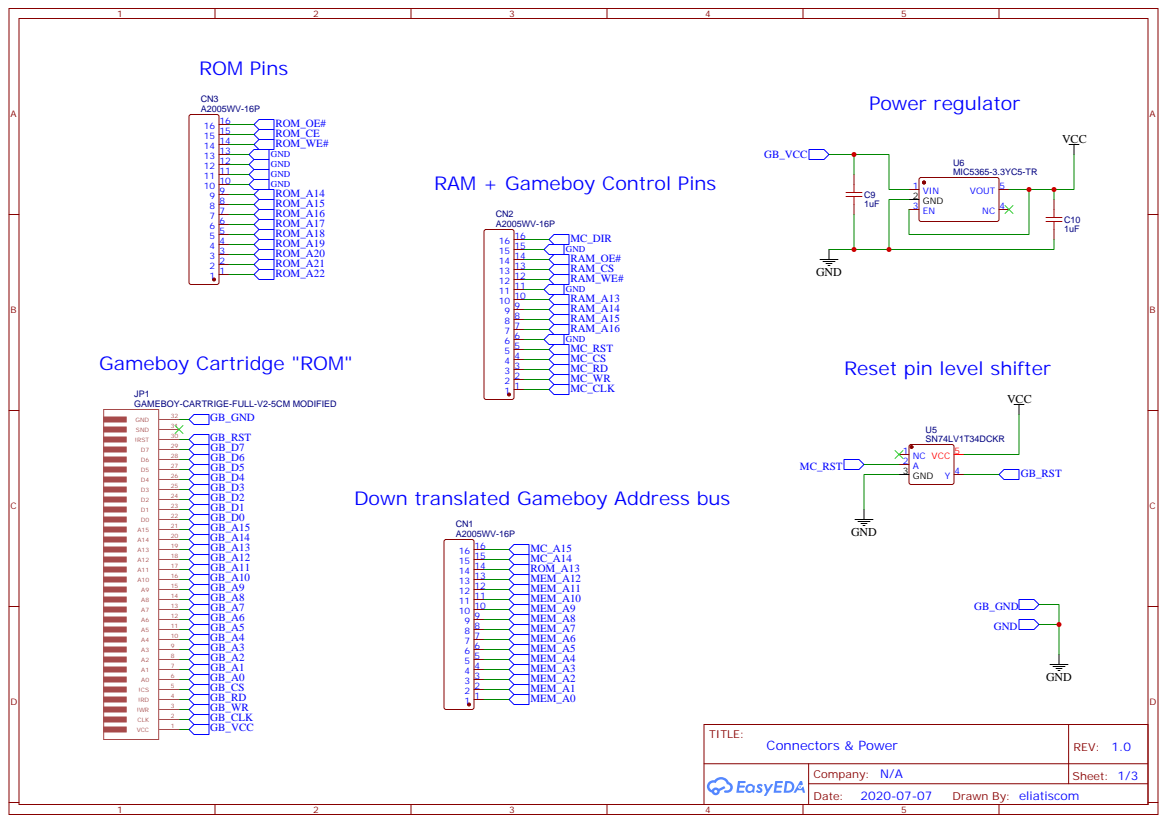
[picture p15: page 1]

Reset pin level shifter

GAMEBOY-CARTRIGE-FULL-V2-5CM MODIFIED

Down translated Gameboy Address bus

# Gameboy Cartridge RAM

# Gameboy Cartridge "ROM"

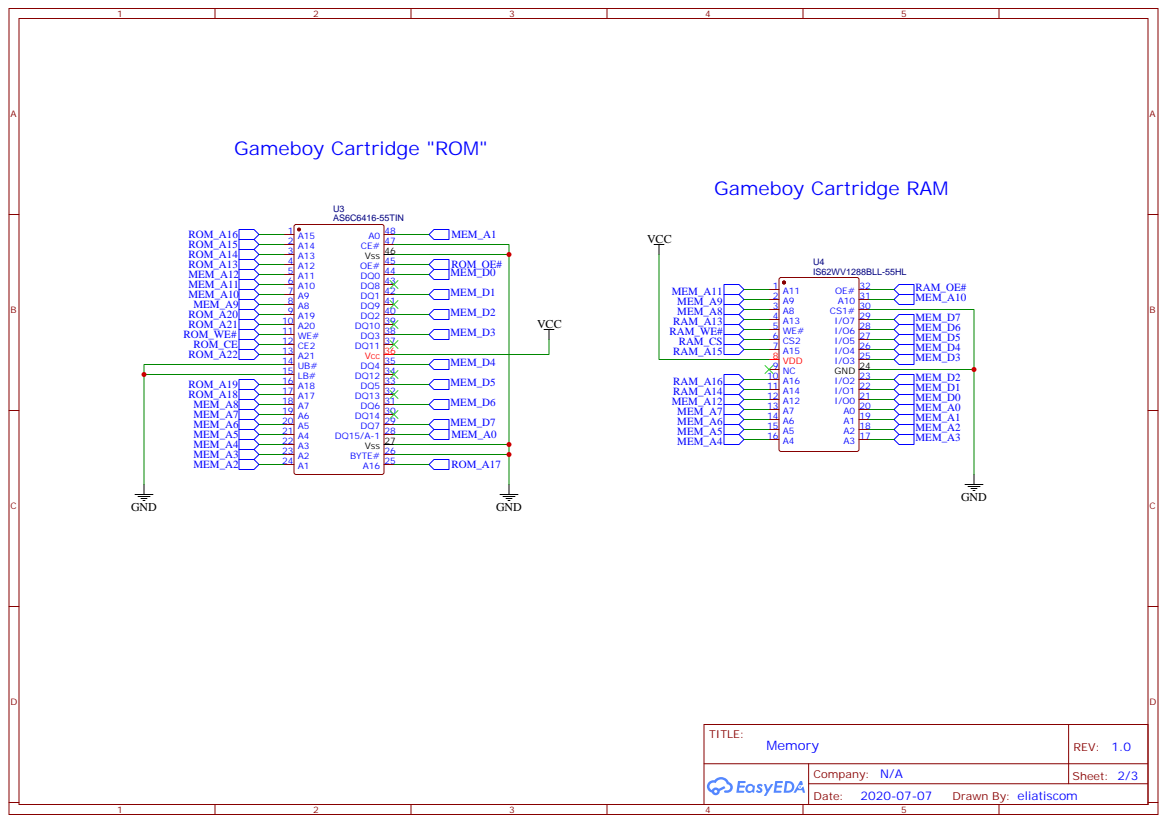
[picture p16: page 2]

2DIR 24 2OE# 25 2A8 26 2A7 27 GND 28 2A6 29 2A5 30 VCC 31 2A4 32 2A3 33 GND 34 2A2 35 2A1 36 1A8 37 1A7 38 GND 39 1A6 40 1A5 41 VCC 42 1A4 43 1A3 44 GND 45 1A2 46 1A1 47 1OE# 48

# Data + Control transceiver

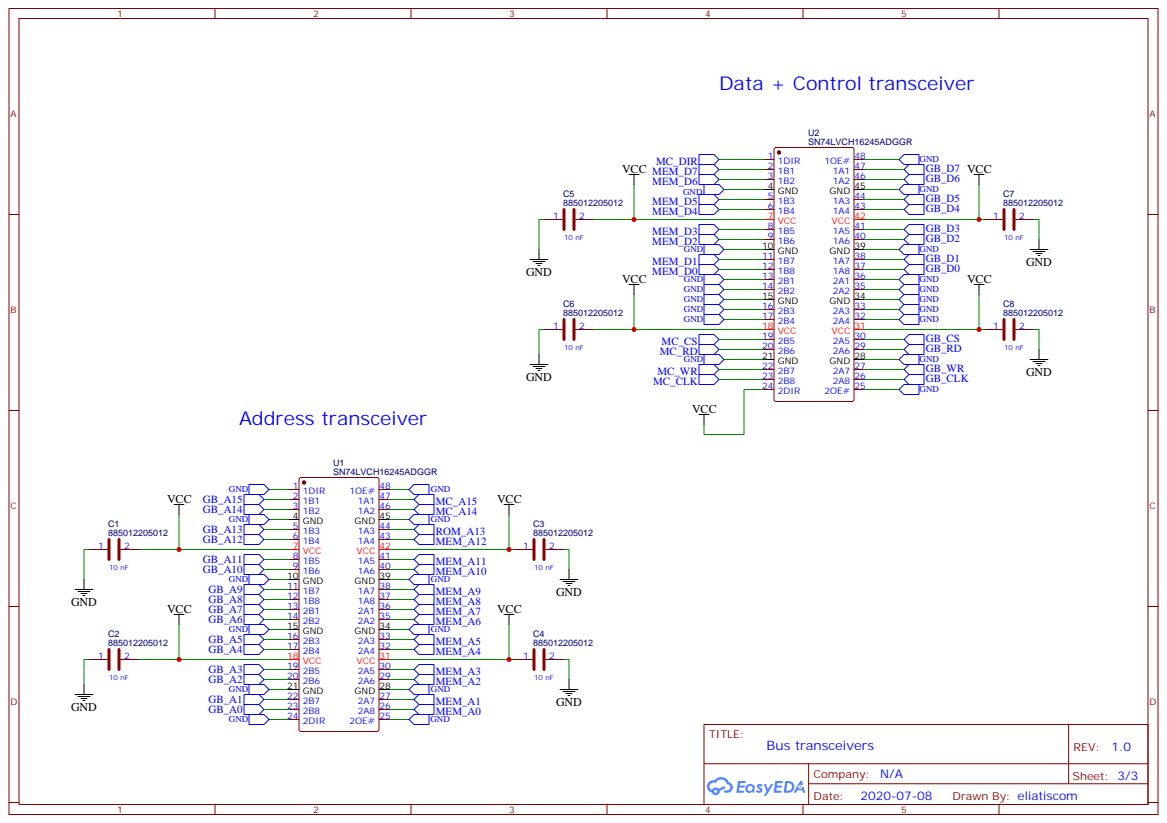
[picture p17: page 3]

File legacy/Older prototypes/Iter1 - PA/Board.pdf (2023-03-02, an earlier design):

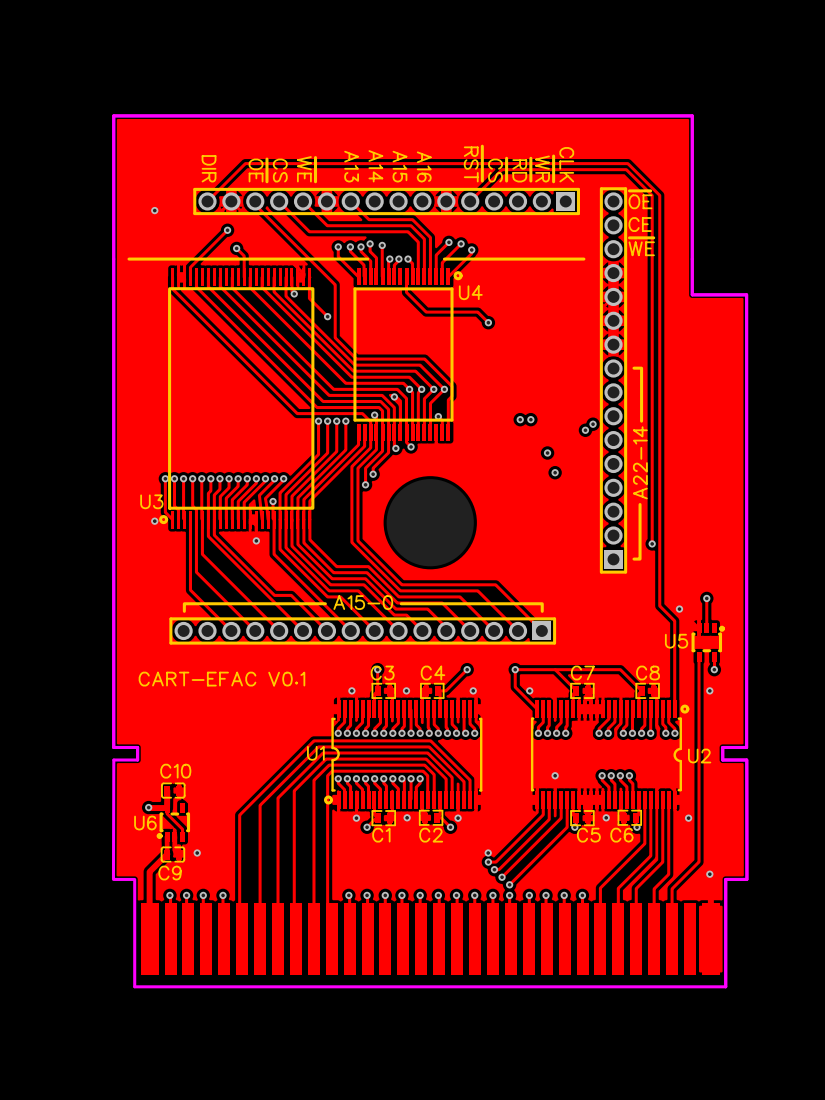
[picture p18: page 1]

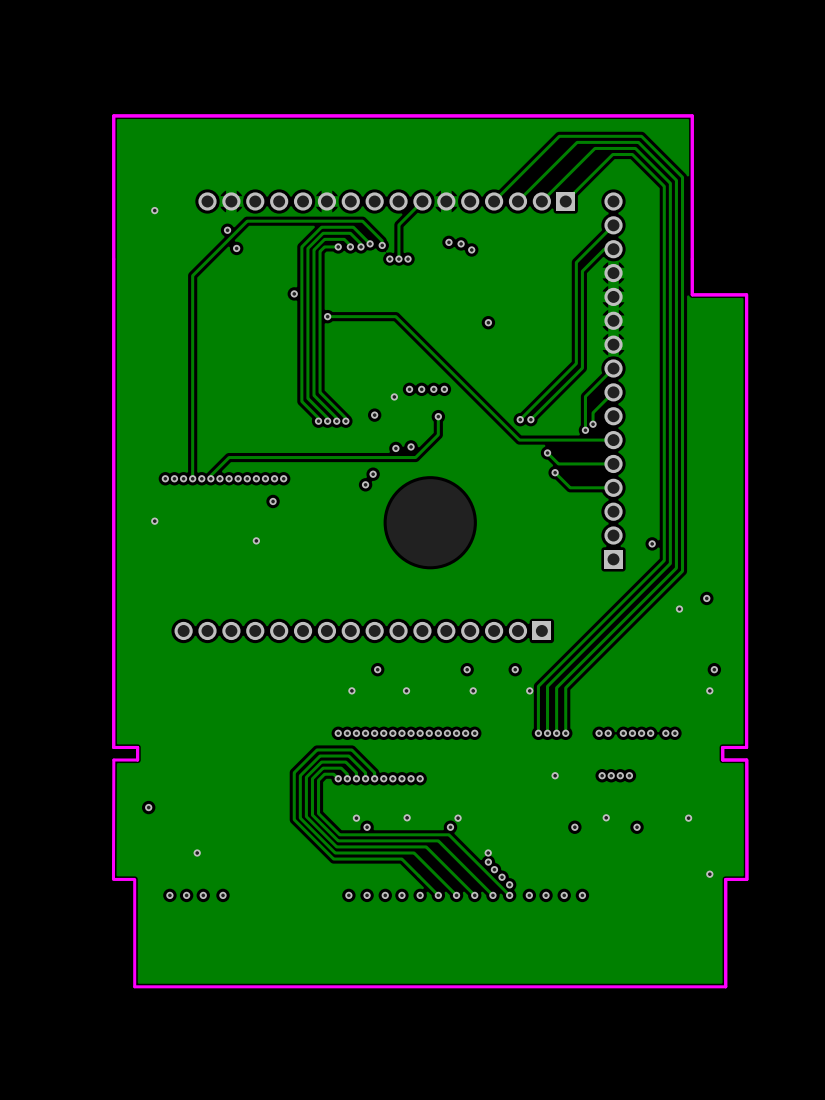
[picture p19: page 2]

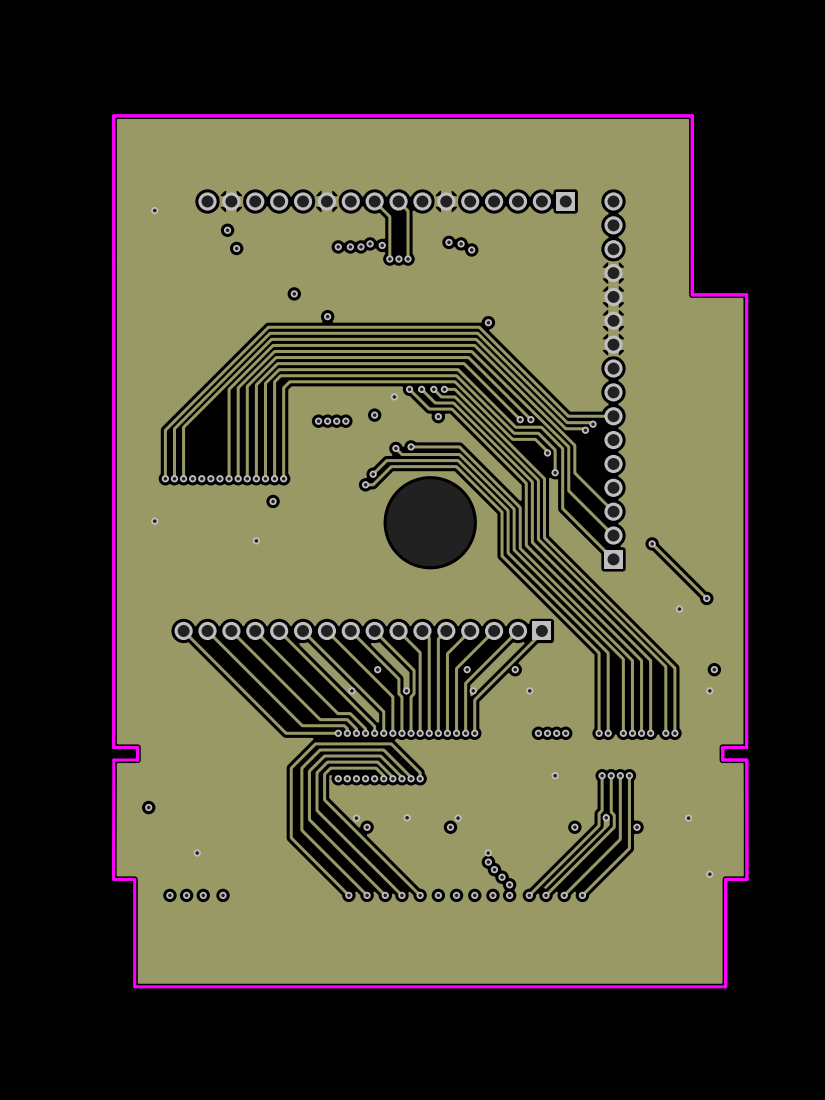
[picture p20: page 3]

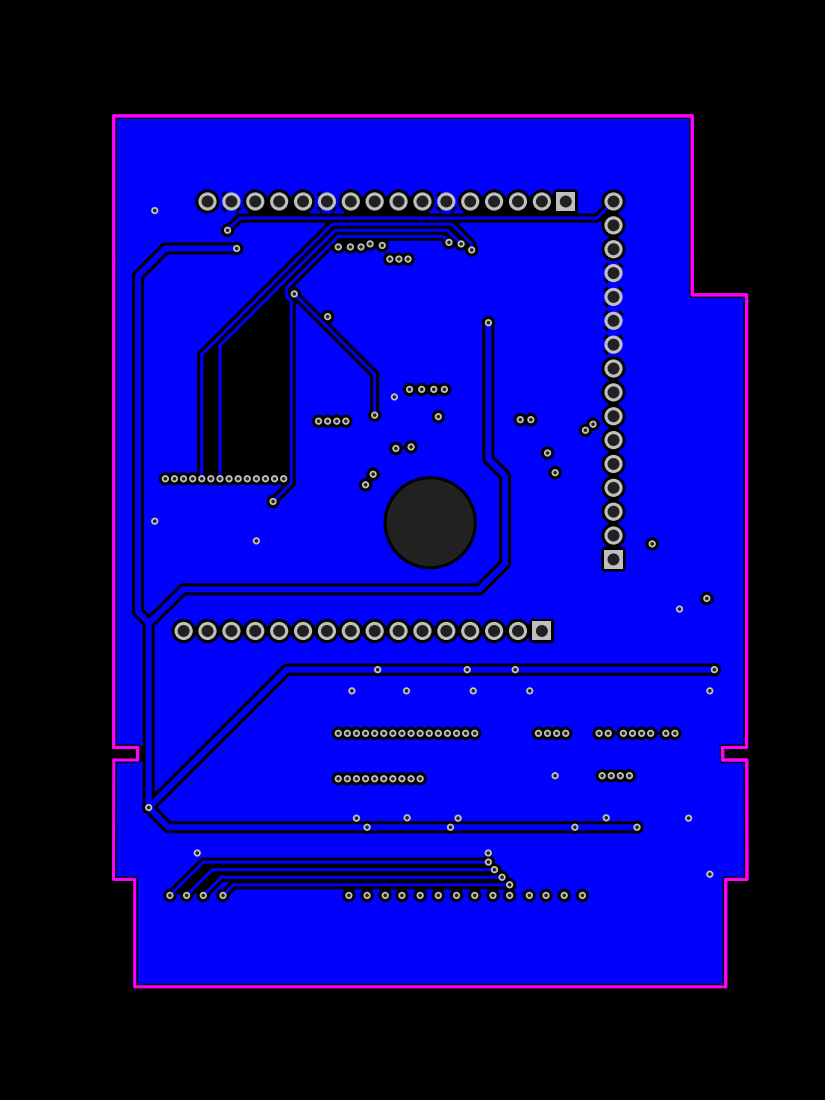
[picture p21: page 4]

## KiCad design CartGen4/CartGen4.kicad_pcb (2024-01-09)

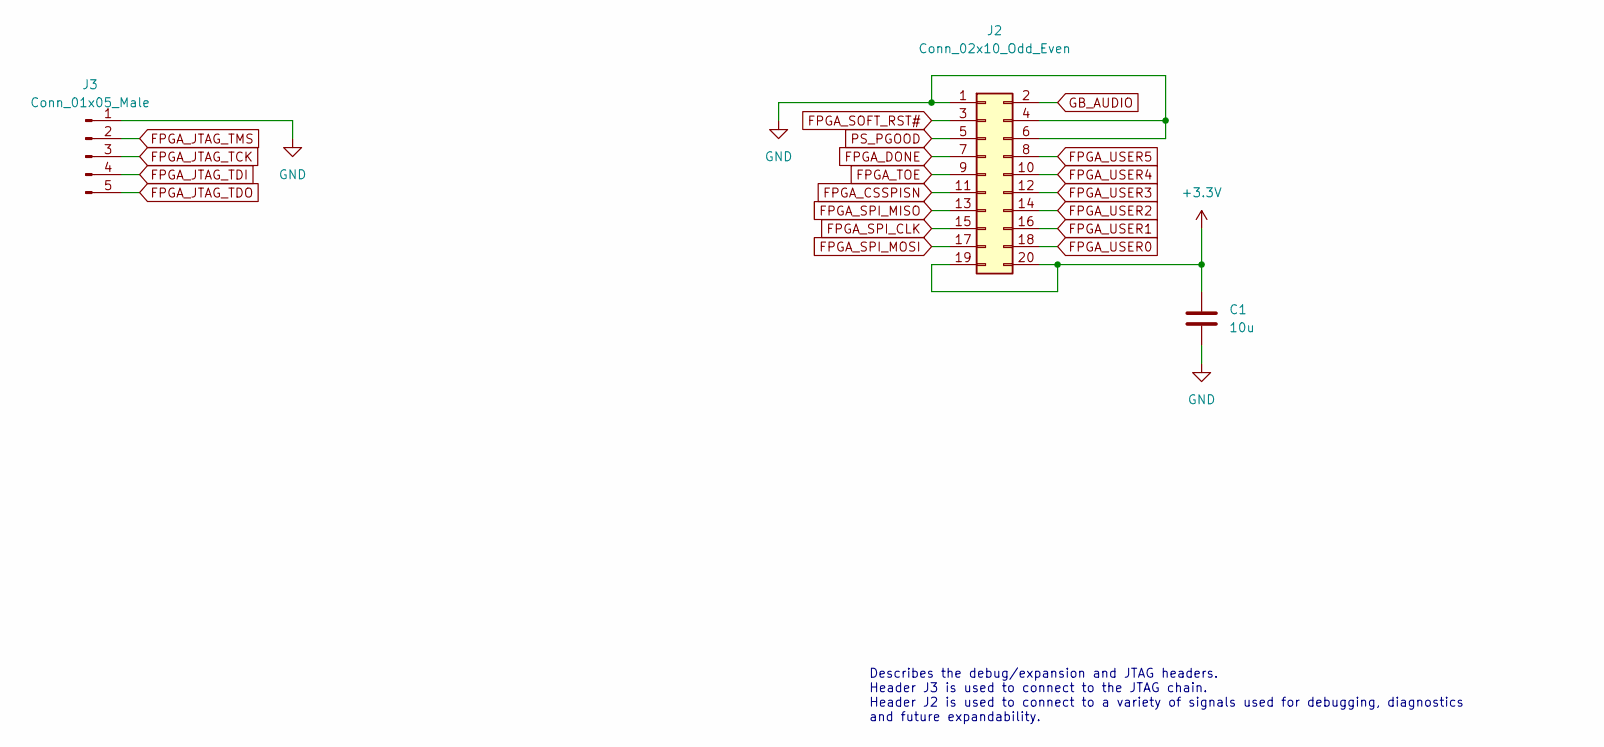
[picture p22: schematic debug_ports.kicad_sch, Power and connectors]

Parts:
C1: 10u; C_0603_1608Metric_Pad1.08x0.95mm_HandSolder; Tolerance 20%; Voltage 10V
J2: Conn_02x10_Odd_Even; Conn_02x10
J3: Conn_01x05_Male; PinHeader_1x05_P1.27mm_Vertical

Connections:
FPGA_CSSPISN: J2.11; also elsewhere on the board
FPGA_DONE: J2.7; also elsewhere on the board
FPGA_JTAG_TCK: J3.3; also elsewhere on the board
FPGA_JTAG_TDI: J3.4; also elsewhere on the board
FPGA_JTAG_TDO: J3.5; also elsewhere on the board
FPGA_JTAG_TMS: J3.2; also elsewhere on the board
FPGA_SOFT_RST#: J2.3; also elsewhere on the board
FPGA_SPI_CLK: J2.15; also elsewhere on the board
FPGA_SPI_MISO: J2.13; also elsewhere on the board
FPGA_SPI_MOSI: J2.17; also elsewhere on the board
FPGA_TOE: J2.9; also elsewhere on the board
FPGA_USER0: J2.18; also elsewhere on the board
FPGA_USER1: J2.16; also elsewhere on the board
FPGA_USER2: J2.14; also elsewhere on the board
FPGA_USER3: J2.12; also elsewhere on the board
FPGA_USER4: J2.10; also elsewhere on the board
FPGA_USER5: J2.8; also elsewhere on the board
GB_AUDIO: J2.2; also elsewhere on the board
GND: C1.2, J2.1, J2.4, J2.6, J3.1; also elsewhere on the board
PS_PGOOD: J2.5; also elsewhere on the board

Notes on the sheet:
Describes the debug/expansion and JTAG headers. Header J3 is used to connect to the JTAG chain. Header J2 is used to connect to a variety of signals used for debugging, diagnostics and future expandability.

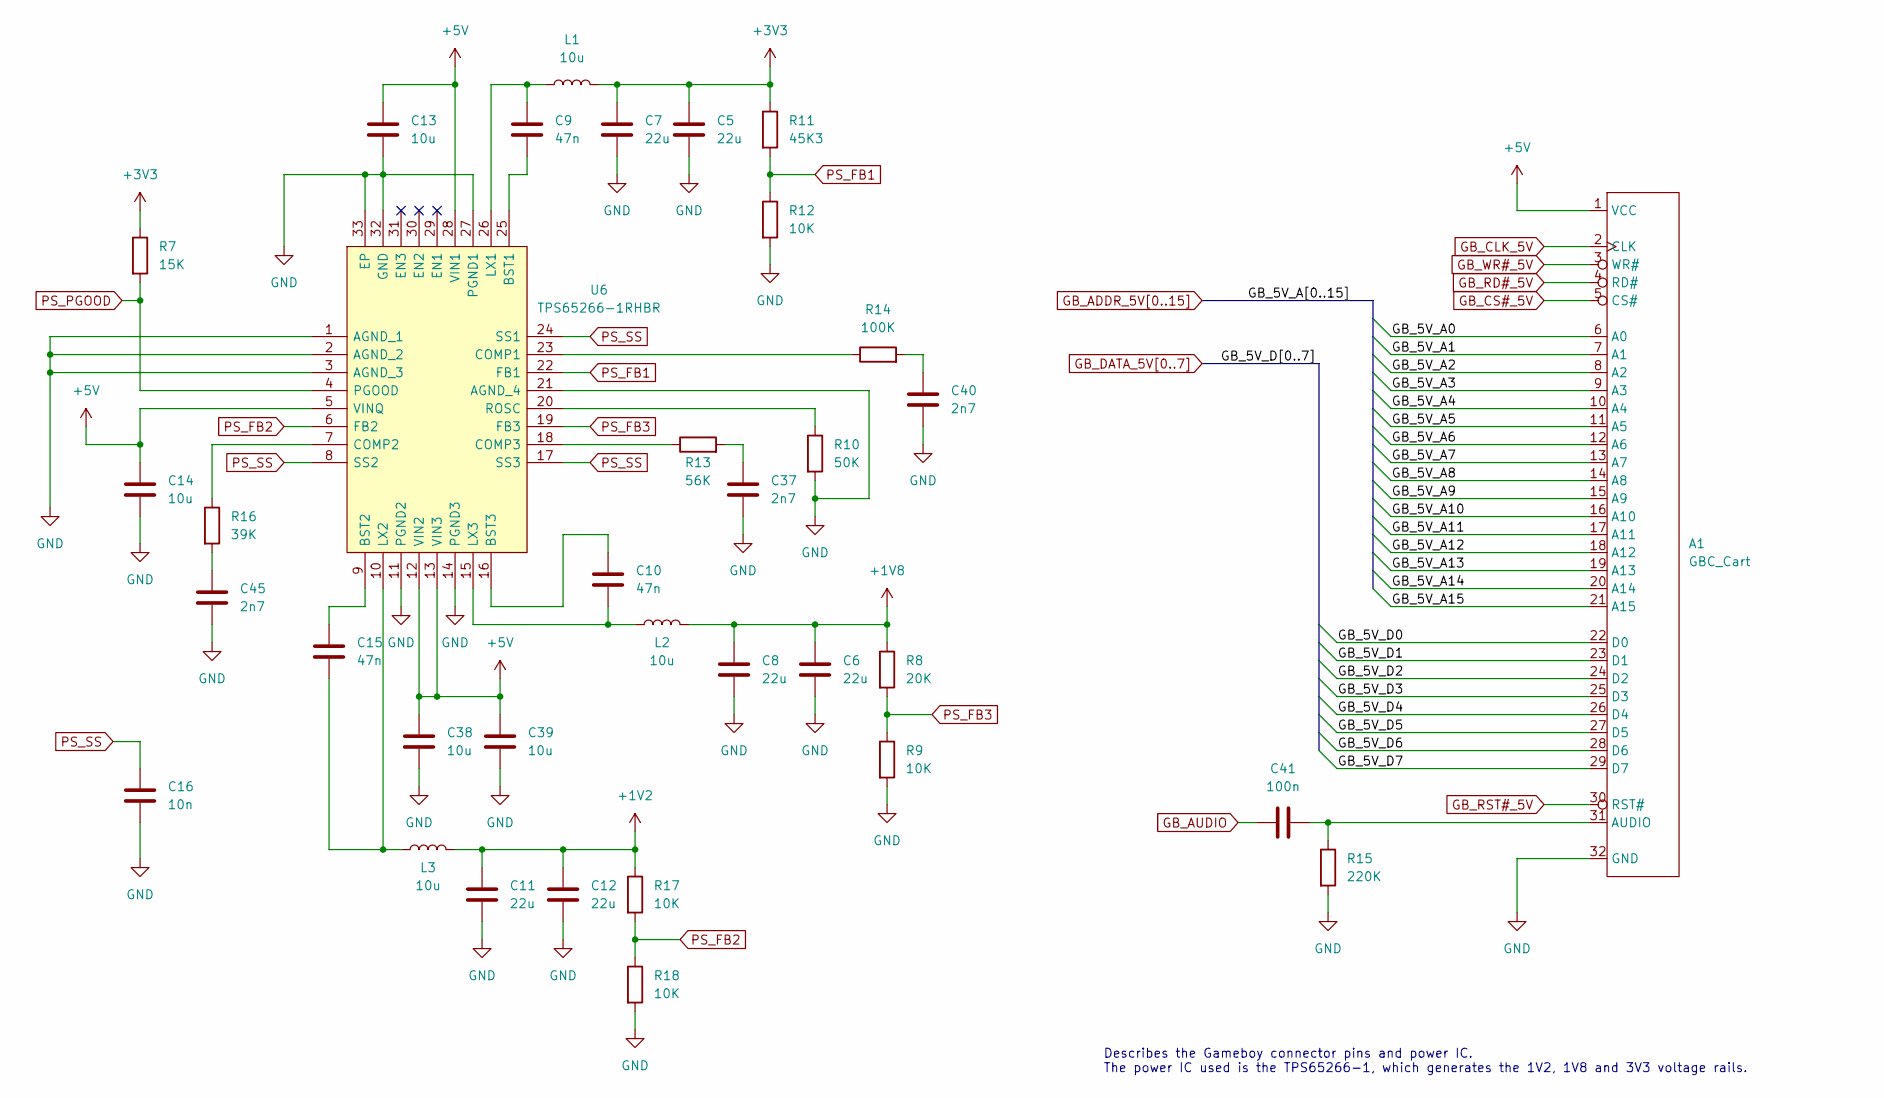
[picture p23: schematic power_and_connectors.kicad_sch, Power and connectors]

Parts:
A1: GBC_Cart
C5, C6, C7, C8, C11, C12: 22u; C_0603_1608Metric_Pad1.08x0.95mm_HandSolder; Tolerance 20%; Voltage 3V3
C9, C10, C15: 47n; C_0402_1005Metric_Pad0.74x0.62mm_HandSolder; Voltage 10V; Tolerance 5%
C13, C14, C38, C39: 10u; C_0603_1608Metric_Pad1.08x0.95mm_HandSolder; Voltage 10V; Tolerance 20%
C16: 10n; C_0402_1005Metric_Pad0.74x0.62mm_HandSolder; Tolerance 20%; Voltage 3V3
C37, C40, C45: 2n7; C_0402_1005Metric_Pad0.74x0.62mm_HandSolder; Tolerance 5%; Voltage 3V3
C41: 100n; C_0603_1608Metric_Pad1.08x0.95mm_HandSolder
L1, L2, L3: 10u; L_1008_2520Metric; Tolerance 20%
R7: 15K; R_0402_1005Metric_Pad0.72x0.64mm_HandSolder; Tolerance 10%
R8: 20K; R_0402_1005Metric_Pad0.72x0.64mm_HandSolder; Tolerance 1%
R9, R12, R17, R18: 10K; R_0402_1005Metric_Pad0.72x0.64mm_HandSolder; Tolerance 1%
R10: 50K; R_0402_1005Metric_Pad0.72x0.64mm_HandSolder; Tolerance 1%
R11: 45K3; R_0402_1005Metric_Pad0.72x0.64mm_HandSolder; Tolerance 1%
R13: 56K; R_0402_1005Metric_Pad0.72x0.64mm_HandSolder; Tolerance 1%
R14: 100K; R_0402_1005Metric_Pad0.72x0.64mm_HandSolder; Tolerance 1%
R15: 220K; R_0402_1005Metric_Pad0.72x0.64mm_HandSolder; Tolerance 10%
R16: 39K; R_0402_1005Metric_Pad0.72x0.64mm_HandSolder; Tolerance 1%
U6: TPS65266-1RHBR; QFN50P500X500X100-33N-D

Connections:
+1V2: C11.1, C12.1, L3.2, R17.1; also elsewhere on the board
+1V8: C6.1, C8.1, L2.2, R8.1; also elsewhere on the board
+5V: A1.1 (VCC), C13.1, C14.1, C38.1, C39.1, U6.5 (VINQ), U6.12 (VIN2), U6.13 (VIN3), U6.28 (VIN1); also elsewhere on the board
GB_ADDR_5V0: A1.6 (A0); also elsewhere on the board
GB_ADDR_5V1: A1.7 (A1); also elsewhere on the board
GB_ADDR_5V2: A1.8 (A2); also elsewhere on the board
GB_ADDR_5V3: A1.9 (A3); also elsewhere on the board
GB_ADDR_5V4: A1.10 (A4); also elsewhere on the board
GB_ADDR_5V5: A1.11 (A5); also elsewhere on the board
GB_ADDR_5V6: A1.12 (A6); also elsewhere on the board
GB_ADDR_5V7: A1.13 (A7); also elsewhere on the board
GB_ADDR_5V8: A1.14 (A8); also elsewhere on the board
GB_ADDR_5V9: A1.15 (A9); also elsewhere on the board
GB_ADDR_5V10: A1.16 (A10); also elsewhere on the board
GB_ADDR_5V11: A1.17 (A11); also elsewhere on the board
GB_ADDR_5V12: A1.18 (A12); also elsewhere on the board
GB_ADDR_5V13: A1.19 (A13); also elsewhere on the board
GB_ADDR_5V14: A1.20 (A14); also elsewhere on the board
GB_ADDR_5V15: A1.21 (A15); also elsewhere on the board
GB_AUDIO: C41.1; also elsewhere on the board
GB_CLK_5V: A1.2 (CLK); also elsewhere on the board
GB_CS#_5V: A1.5 (CS#); also elsewhere on the board
GB_DATA_5V0: A1.22 (D0); also elsewhere on the board
GB_DATA_5V1: A1.23 (D1); also elsewhere on the board
GB_DATA_5V2: A1.24 (D2); also elsewhere on the board
GB_DATA_5V3: A1.25 (D3); also elsewhere on the board
GB_DATA_5V4: A1.26 (D4); also elsewhere on the board
GB_DATA_5V5: A1.27 (D5); also elsewhere on the board
GB_DATA_5V6: A1.28 (D6); also elsewhere on the board
GB_DATA_5V7: A1.29 (D7); also elsewhere on the board
GB_RD#_5V: A1.4 (RD#); also elsewhere on the board
GB_RST#_5V: A1.30 (RST#); also elsewhere on the board
GB_WR#_5V: A1.3 (WR#); also elsewhere on the board
GND: A1.32 (GND), C5.2, C6.2, C7.2, C8.2, C11.2, C12.2, C13.2, C14.2, C16.2, C37.2, C38.2, C39.2, C40.2, C45.2, R9.2, R10.2, R12.2, R15.2, R18.2, U6.1 (AGND_1), U6.2 (AGND_2), U6.3 (AGND_3), U6.11 (PGND2), U6.14 (PGND3), U6.21 (AGND_4), U6.27 (PGND1), U6.32 (GND), U6.33 (EP); also elsewhere on the board
unnamed: A1.31 (AUDIO), C41.2, R15.1
unnamed: C45.1, R16.2
unnamed: C15.1, U6.9 (BST2)
unnamed: C15.2, L3.1, U6.10 (LX2)
unnamed: C9.1, L1.1, U6.26 (LX1)
unnamed: C9.2, U6.25 (BST1)
unnamed: C10.1, U6.16 (BST3)
unnamed: C10.2, L2.1, U6.15 (LX3)
unnamed: C37.1, R13.2
unnamed: C40.1, R14.2
unnamed: R16.1, U6.7 (COMP2)
unnamed: R13.1, U6.18 (COMP3)
unnamed: R10.1, U6.20 (ROSC)
unnamed: R14.1, U6.23 (COMP1)
PS_FB1: R11.2, R12.1, U6.22 (FB1)
PS_FB2: R17.2, R18.1, U6.6 (FB2)
PS_FB3: R8.2, R9.1, U6.19 (FB3)
PS_PGOOD: R7.2, U6.4 (PGOOD); also elsewhere on the board
PS_SS: C16.1, U6.8 (SS2), U6.17 (SS3), U6.24 (SS1)

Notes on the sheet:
Describes the Gameboy connector pins and power IC. The power IC used is the TPS65266-1, which generates the 1V2, 1V8 and 3V3 voltage rails.

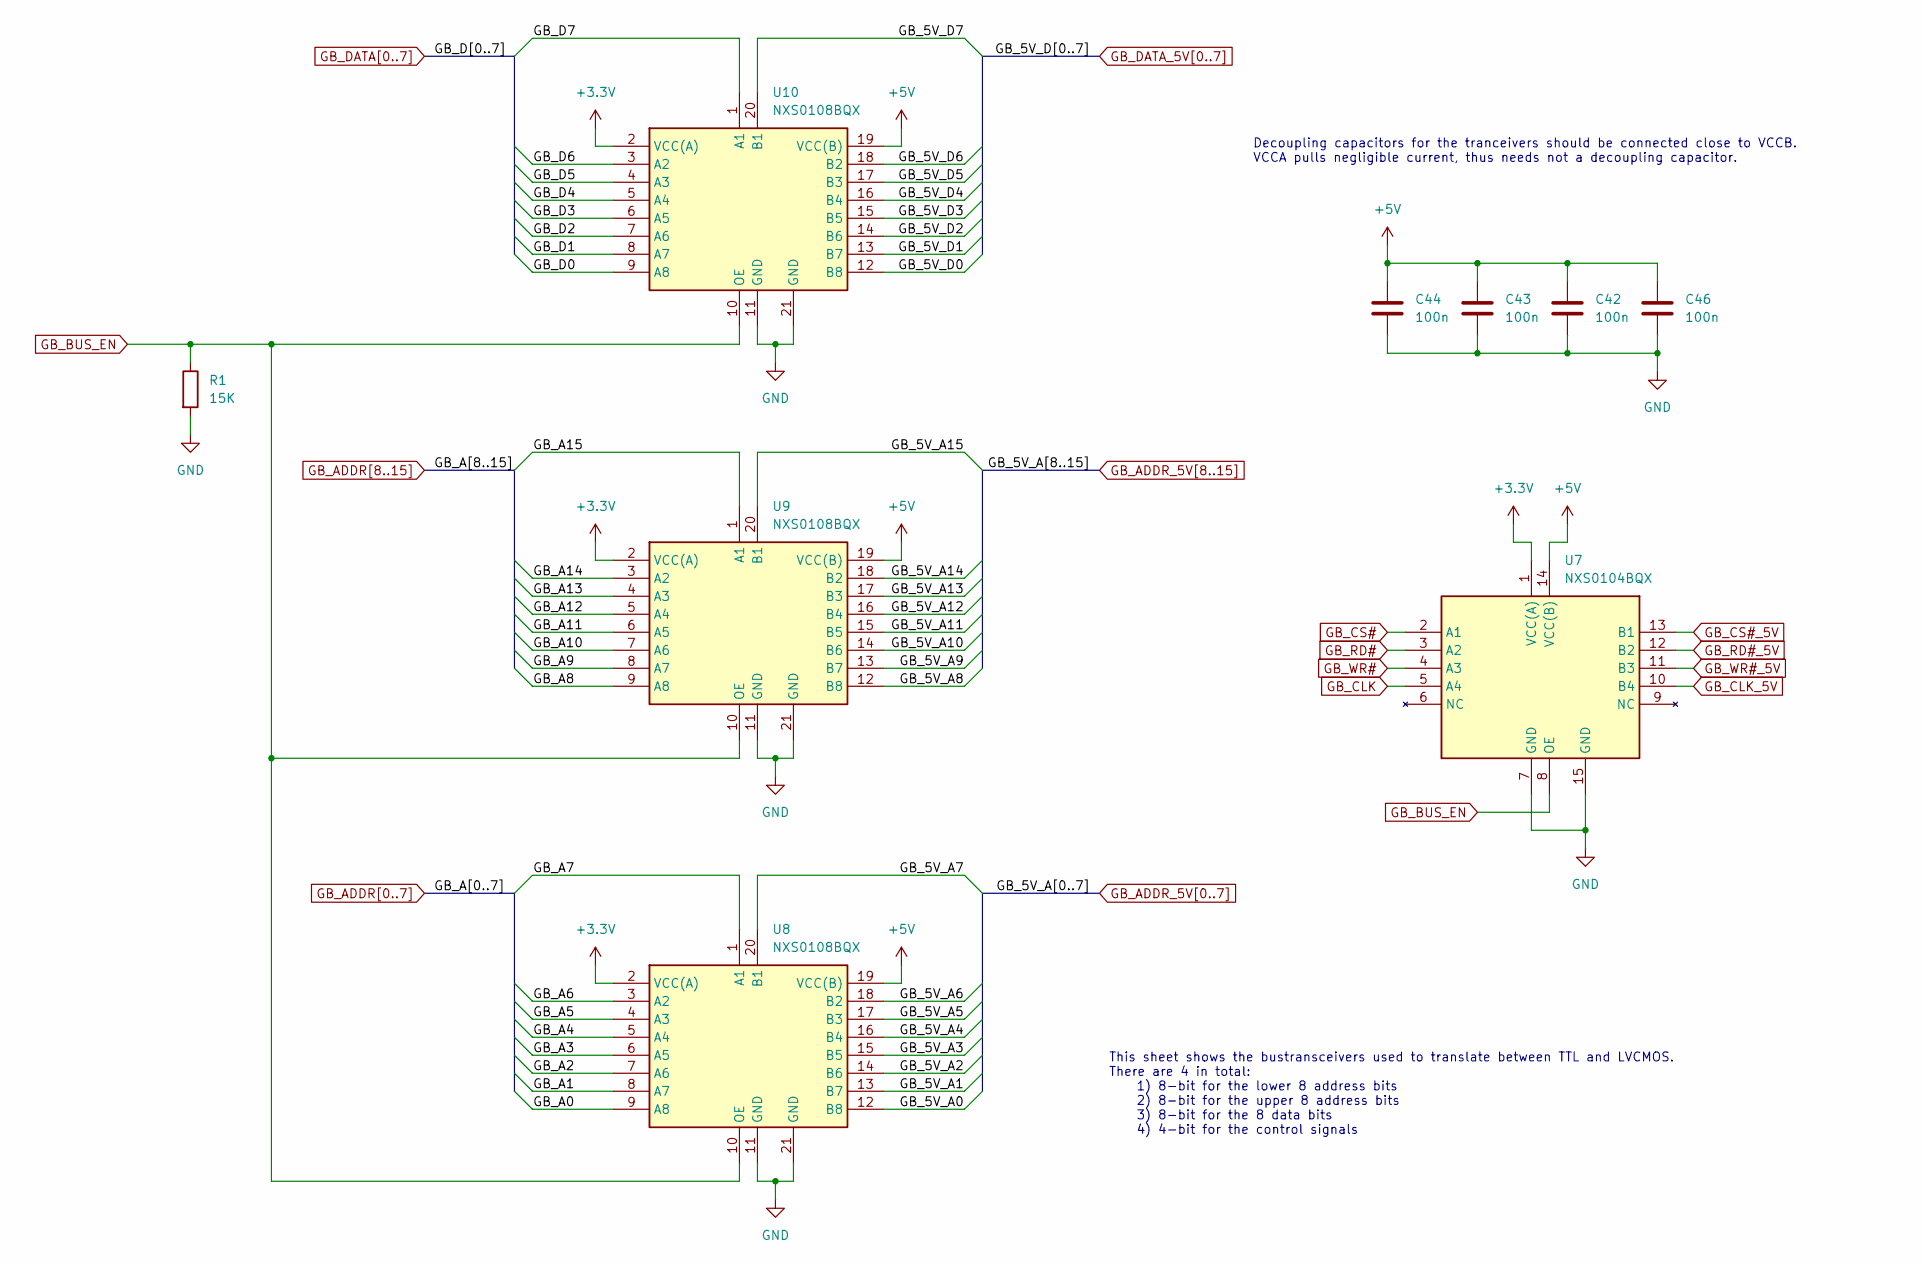
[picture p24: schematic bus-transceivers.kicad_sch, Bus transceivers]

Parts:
C42, C43, C44, C46: 100n; C_0402_1005Metric_Pad0.74x0.62mm_HandSolder; Tolerance 20%; Voltage 3V3
R1: 15K; R_0402_1005Metric_Pad0.72x0.64mm_HandSolder; Tolerance 10%
U7: NXS0104BQX
U8, U9, U10: NXS0108BQX

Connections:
+5V: C42.1, C43.1, C44.1, C46.1, U7.14 (VCC(B)), U8.19 (VCC(B)), U9.19 (VCC(B)), U10.19 (VCC(B)); also elsewhere on the board
GB_ADDR0: U8.9 (A8); also elsewhere on the board
GB_ADDR1: U8.8 (A7); also elsewhere on the board
GB_ADDR2: U8.7 (A6); also elsewhere on the board
GB_ADDR3: U8.6 (A5); also elsewhere on the board
GB_ADDR4: U8.5 (A4); also elsewhere on the board
GB_ADDR5: U8.4 (A3); also elsewhere on the board
GB_ADDR6: U8.3 (A2); also elsewhere on the board
GB_ADDR7: U8.1 (A1); also elsewhere on the board
GB_ADDR8: U9.9 (A8); also elsewhere on the board
GB_ADDR9: U9.8 (A7); also elsewhere on the board
GB_ADDR10: U9.7 (A6); also elsewhere on the board
GB_ADDR11: U9.6 (A5); also elsewhere on the board
GB_ADDR12: U9.5 (A4); also elsewhere on the board
GB_ADDR13: U9.4 (A3); also elsewhere on the board
GB_ADDR14: U9.3 (A2); also elsewhere on the board
GB_ADDR15: U9.1 (A1); also elsewhere on the board
GB_ADDR_5V0: U8.12 (B8); also elsewhere on the board
GB_ADDR_5V1: U8.13 (B7); also elsewhere on the board
GB_ADDR_5V2: U8.14 (B6); also elsewhere on the board
GB_ADDR_5V3: U8.15 (B5); also elsewhere on the board
GB_ADDR_5V4: U8.16 (B4); also elsewhere on the board
GB_ADDR_5V5: U8.17 (B3); also elsewhere on the board
GB_ADDR_5V6: U8.18 (B2); also elsewhere on the board
GB_ADDR_5V7: U8.20 (B1); also elsewhere on the board
GB_ADDR_5V8: U9.12 (B8); also elsewhere on the board
GB_ADDR_5V9: U9.13 (B7); also elsewhere on the board
GB_ADDR_5V10: U9.14 (B6); also elsewhere on the board
GB_ADDR_5V11: U9.15 (B5); also elsewhere on the board
GB_ADDR_5V12: U9.16 (B4); also elsewhere on the board
GB_ADDR_5V13: U9.17 (B3); also elsewhere on the board
GB_ADDR_5V14: U9.18 (B2); also elsewhere on the board
GB_ADDR_5V15: U9.20 (B1); also elsewhere on the board
GB_BUS_EN: R1.1, U7.8 (OE), U8.10 (OE), U9.10 (OE), U10.10 (OE); also elsewhere on the board
GB_CLK: U7.5 (A4); also elsewhere on the board
GB_CLK_5V: U7.10 (B4); also elsewhere on the board
GB_CS#: U7.2 (A1); also elsewhere on the board
GB_CS#_5V: U7.13 (B1); also elsewhere on the board
GB_DATA0: U10.9 (A8); also elsewhere on the board
GB_DATA1: U10.8 (A7); also elsewhere on the board
GB_DATA2: U10.7 (A6); also elsewhere on the board
GB_DATA3: U10.6 (A5); also elsewhere on the board
GB_DATA4: U10.5 (A4); also elsewhere on the board
GB_DATA5: U10.4 (A3); also elsewhere on the board
GB_DATA6: U10.3 (A2); also elsewhere on the board
GB_DATA7: U10.1 (A1); also elsewhere on the board
GB_DATA_5V0: U10.12 (B8); also elsewhere on the board
GB_DATA_5V1: U10.13 (B7); also elsewhere on the board
GB_DATA_5V2: U10.14 (B6); also elsewhere on the board
GB_DATA_5V3: U10.15 (B5); also elsewhere on the board
GB_DATA_5V4: U10.16 (B4); also elsewhere on the board
GB_DATA_5V5: U10.17 (B3); also elsewhere on the board
GB_DATA_5V6: U10.18 (B2); also elsewhere on the board
GB_DATA_5V7: U10.20 (B1); also elsewhere on the board
GB_RD#: U7.3 (A2); also elsewhere on the board
GB_RD#_5V: U7.12 (B2); also elsewhere on the board
GB_WR#: U7.4 (A3); also elsewhere on the board
GB_WR#_5V: U7.11 (B3); also elsewhere on the board
GND: C42.2, C43.2, C44.2, C46.2, R1.2, U7.7 (GND), U7.15 (GND), U8.11 (GND), U8.21 (GND), U9.11 (GND), U9.21 (GND), U10.11 (GND), U10.21 (GND); also elsewhere on the board

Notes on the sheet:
This sheet shows the bustransceivers used to translate between TTL and LVCMOS. There are 4 in total: 1) 8-bit for the lower 8 address bits 2) 8-bit for the upper 8 address bits 3) 8-bit for the 8 data bits 4) 4-bit for the control signals
Decoupling capacitors for the tranceivers should be connected close to VCCB. VCCA pulls negligible current, thus needs not a decoupling capacitor.

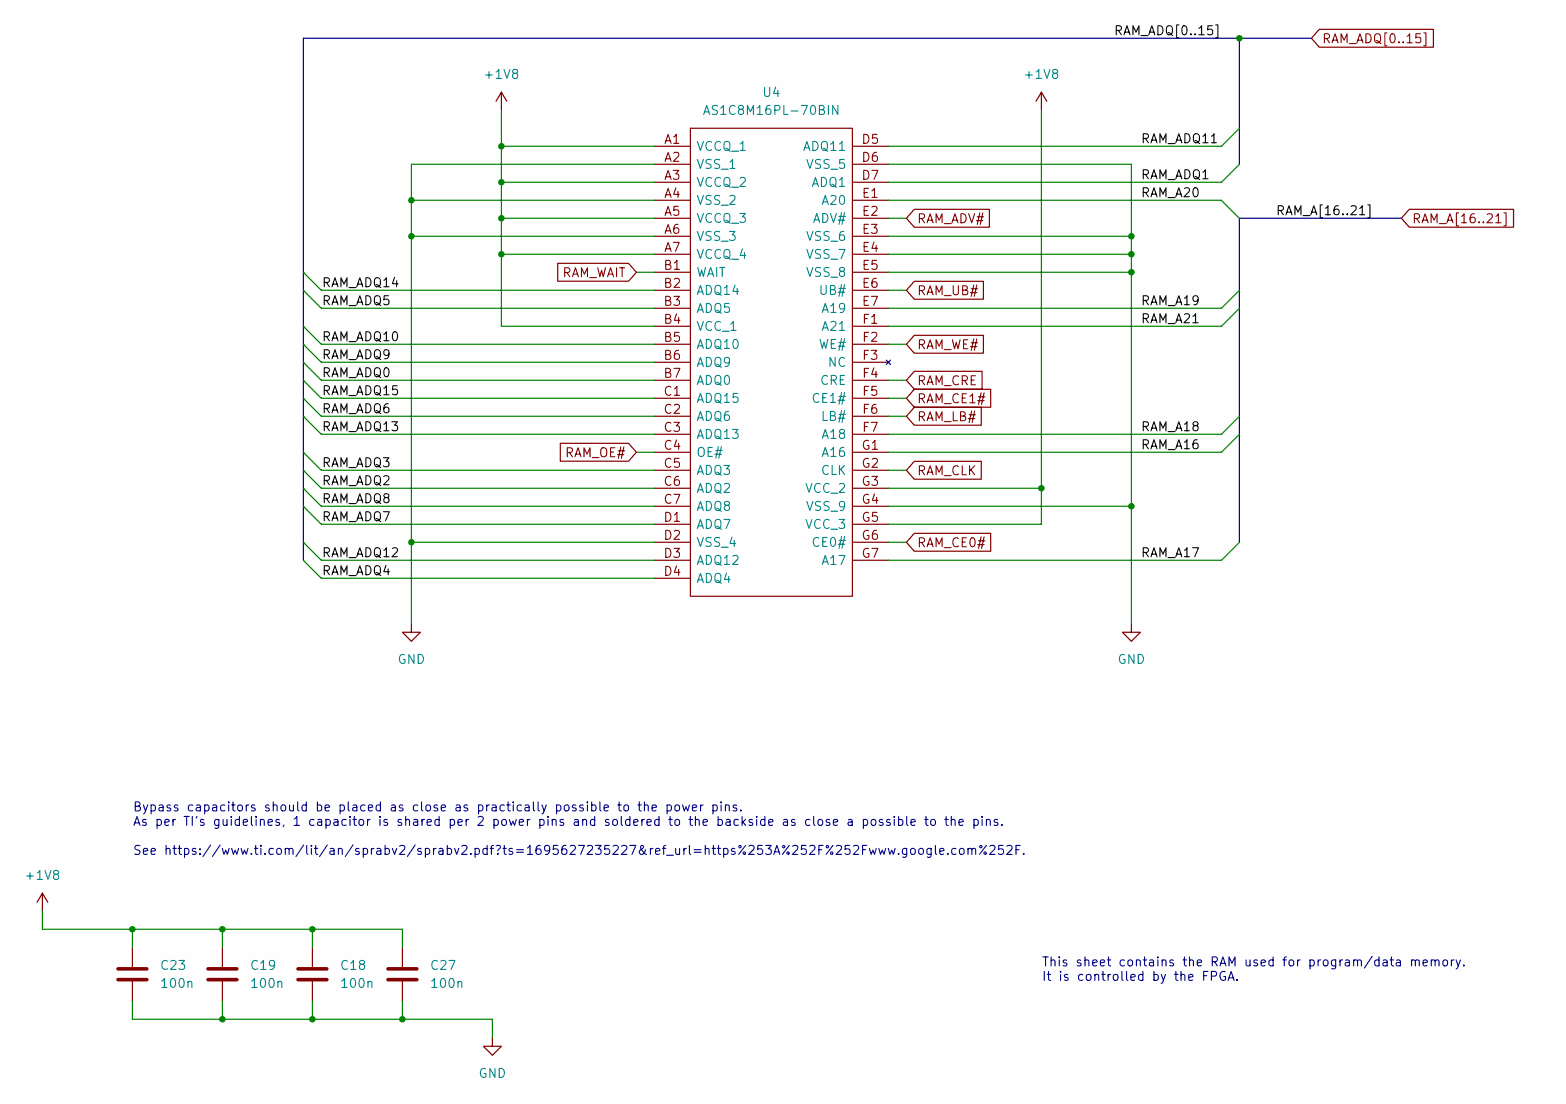
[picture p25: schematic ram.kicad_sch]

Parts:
C18, C19, C23, C27: 100n; C_0402_1005Metric_Pad0.74x0.62mm_HandSolder; Tolerance 20%; Voltage 3V3
U4: AS1C8M16PL-70BIN; BGA49C50P7X7_400X400X100

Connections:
+1V8: C18.1, C19.1, C23.1, C27.1, U4.A1 (VCCQ_1), U4.A3 (VCCQ_2), U4.A5 (VCCQ_3), U4.A7 (VCCQ_4), U4.B4 (VCC_1), U4.G3 (VCC_2), U4.G5 (VCC_3); also elsewhere on the board
GND: C18.2, C19.2, C23.2, C27.2, U4.A2 (VSS_1), U4.A4 (VSS_2), U4.A6 (VSS_3), U4.D2 (VSS_4), U4.D6 (VSS_5), U4.E3 (VSS_6), U4.E4 (VSS_7), U4.E5 (VSS_8), U4.G4 (VSS_9); also elsewhere on the board
RAM_A16: U4.G1 (A16); also elsewhere on the board
RAM_A17: U4.G7 (A17); also elsewhere on the board
RAM_A18: U4.F7 (A18); also elsewhere on the board
RAM_A19: U4.E7 (A19); also elsewhere on the board
RAM_A20: U4.E1 (A20); also elsewhere on the board
RAM_A21: U4.F1 (A21); also elsewhere on the board
RAM_ADQ0: U4.B7 (ADQ0); also elsewhere on the board
RAM_ADQ1: U4.D7 (ADQ1); also elsewhere on the board
RAM_ADQ2: U4.C6 (ADQ2); also elsewhere on the board
RAM_ADQ3: U4.C5 (ADQ3); also elsewhere on the board
RAM_ADQ4: U4.D4 (ADQ4); also elsewhere on the board
RAM_ADQ5: U4.B3 (ADQ5); also elsewhere on the board
RAM_ADQ6: U4.C2 (ADQ6); also elsewhere on the board
RAM_ADQ7: U4.D1 (ADQ7); also elsewhere on the board
RAM_ADQ8: U4.C7 (ADQ8); also elsewhere on the board
RAM_ADQ9: U4.B6 (ADQ9); also elsewhere on the board
RAM_ADQ10: U4.B5 (ADQ10); also elsewhere on the board
RAM_ADQ11: U4.D5 (ADQ11); also elsewhere on the board
RAM_ADQ12: U4.D3 (ADQ12); also elsewhere on the board
RAM_ADQ13: U4.C3 (ADQ13); also elsewhere on the board
RAM_ADQ14: U4.B2 (ADQ14); also elsewhere on the board
RAM_ADQ15: U4.C1 (ADQ15); also elsewhere on the board
RAM_ADV#: U4.E2 (ADV#); also elsewhere on the board
RAM_CE0#: U4.G6 (CE0#); also elsewhere on the board
RAM_CE1#: U4.F5 (CE1#); also elsewhere on the board
RAM_CLK: U4.G2 (CLK); also elsewhere on the board
RAM_CRE: U4.F4 (CRE); also elsewhere on the board
RAM_LB#: U4.F6 (LB#); also elsewhere on the board
RAM_OE#: U4.C4 (OE#); also elsewhere on the board
RAM_UB#: U4.E6 (UB#); also elsewhere on the board
RAM_WAIT: U4.B1 (WAIT); also elsewhere on the board
RAM_WE#: U4.F2 (WE#); also elsewhere on the board

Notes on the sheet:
This sheet contains the RAM used for program/data memory. It is controlled by the FPGA.
Bypass capacitors should be placed as close as practically possible to the power pins. As per TI's guidelines, 1 capacitor is shared per 2 power pins and soldered to the backside as close a possible to the pins. See https://www.ti.com/lit/an/sprabv2/sprabv2.pdf?ts=1695627235227&ref_url=https%253A%2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

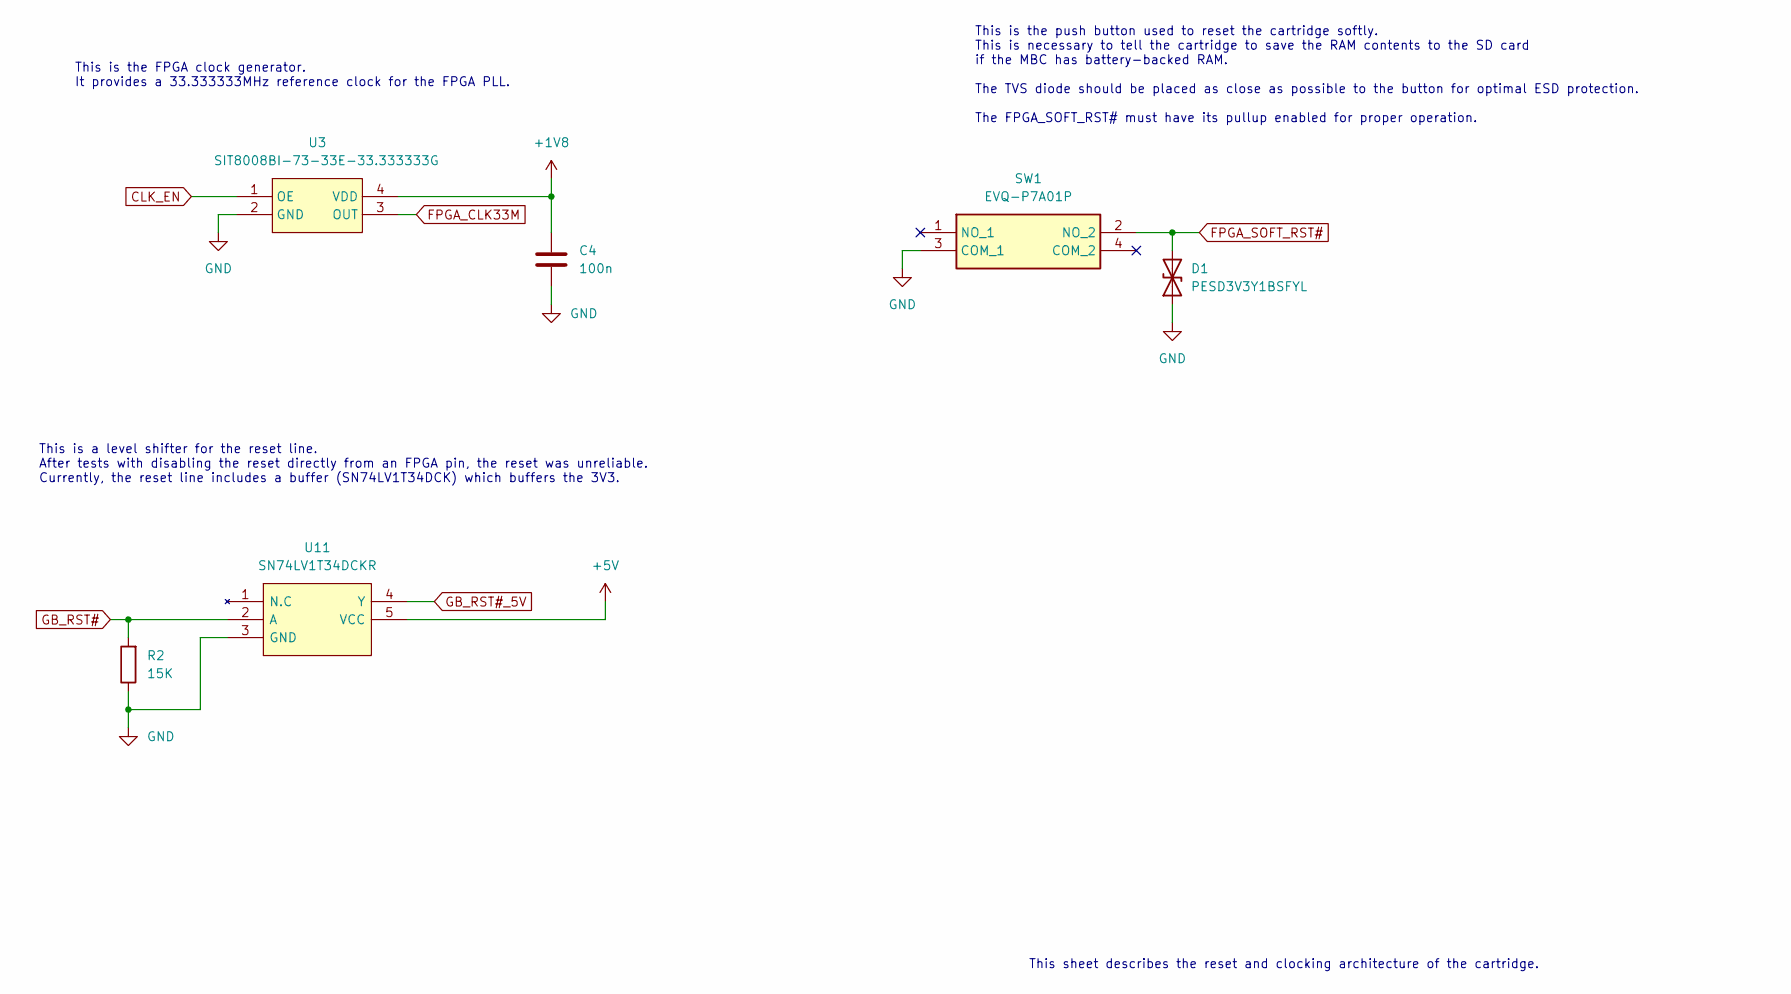
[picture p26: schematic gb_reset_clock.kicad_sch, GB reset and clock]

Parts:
C4: 100n; C_0402_1005Metric_Pad0.74x0.62mm_HandSolder; Tolerance 20%; Voltage 3V3
D1: PESD3V3Y1BSFYL; Voltage 3V3
R2: 15K; R_0402_1005Metric_Pad0.72x0.64mm_HandSolder; Tolerance 10%
SW1: EVQ-P7A01P; EVQP7J01P
U3: SIT8008BI-73-33E-33.333333G
U11: SN74LV1T34DCKR; SOT65P210X110-5N

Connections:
+1V8: C4.1, U3.4 (VDD); also elsewhere on the board
+5V: U11.5 (VCC); also elsewhere on the board
CLK_EN: U3.1 (OE); also elsewhere on the board
FPGA_CLK33M: U3.3 (OUT); also elsewhere on the board
FPGA_SOFT_RST#: D1.2 (A2), SW1.2 (NO_2); also elsewhere on the board
GB_RST#: R2.2, U11.2 (A); also elsewhere on the board
GB_RST#_5V: U11.4 (Y); also elsewhere on the board
GND: C4.2, D1.1 (A1), R2.1, SW1.3 (COM_1), U3.2 (GND), U11.3 (GND); also elsewhere on the board

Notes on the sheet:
This is the push button used to reset the cartridge softly. This is necessary to tell the cartridge to save the RAM contents to the SD card if the MBC has battery-backed RAM. The TVS diode should be placed as close as possible to the button for optimal ESD protection. The FPGA_SOFT_RST# must have i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
This is a level shifter for the reset line. After tests with disabling the reset directly from an FPGA pin, the reset was unreliable. Currently, the reset line includes a buffer (SN74LV1T34DCK) which buffers the 3V3.
This sheet describes the reset and clocking architecture of the cartridge.
This is the FPGA clock generator. It provides a 33.333333MHz reference clock for the FPGA PLL.

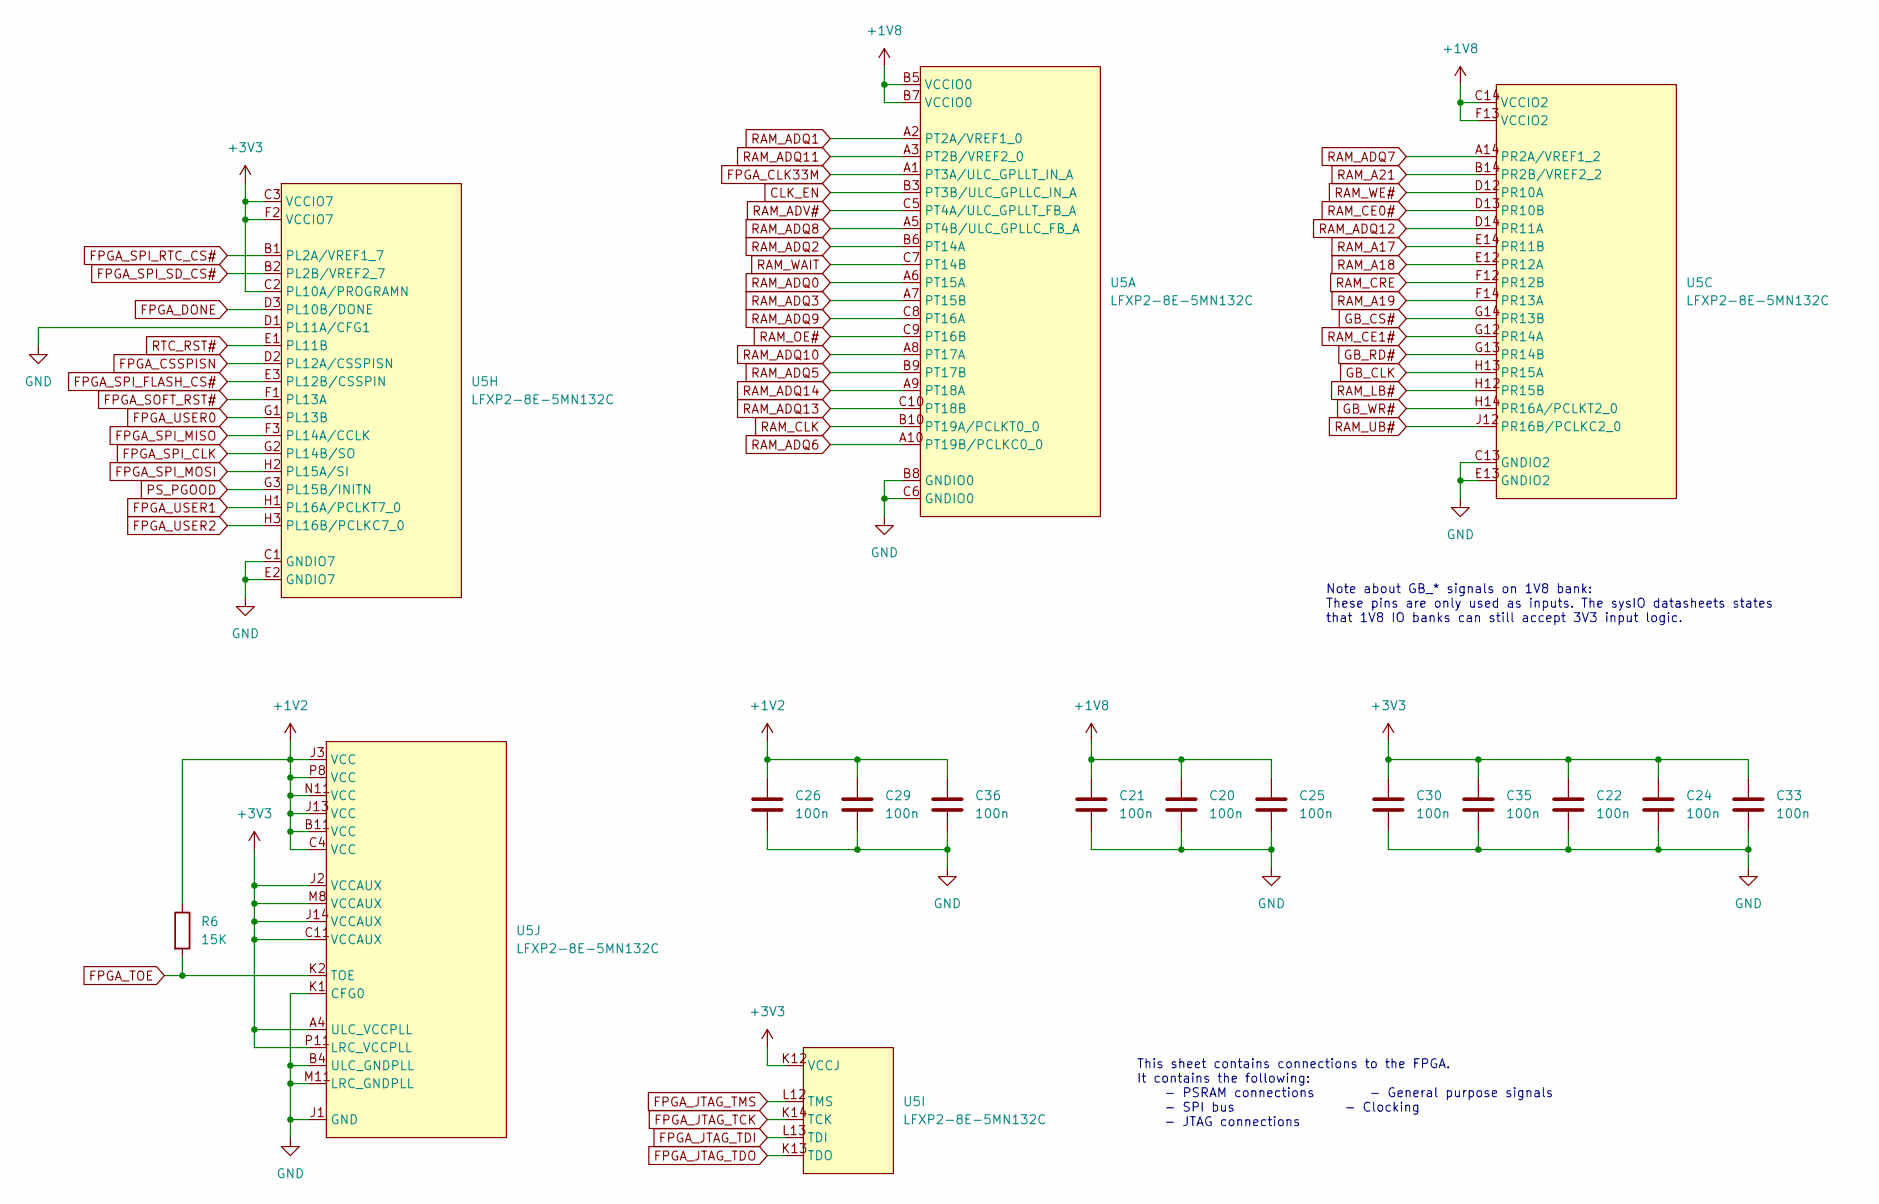
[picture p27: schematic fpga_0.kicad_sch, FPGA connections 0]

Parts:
C20, C21, C22, C24, C25, C26, C29, C30, C33, C35, C36: 100n; C_0402_1005Metric_Pad0.74x0.62mm_HandSolder; Tolerance 20%; Voltage 3V3
R6: 15K; R_0402_1005Metric_Pad0.72x0.64mm_HandSolder; Tolerance 10%
U5: LFXP2-8E-5MN132C; BGA132C50P14X14_800X800X135

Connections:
+1V2: C26.1, C29.1, C36.1, R6.1, U5.B11 (VCC), U5.C4 (VCC), U5.J3 (VCC), U5.J13 (VCC), U5.N11 (VCC), U5.P8 (VCC); also elsewhere on the board
+1V8: C20.1, C21.1, C25.1, U5.B5 (VCCIO0), U5.B7 (VCCIO0), U5.C14 (VCCIO2), U5.F13 (VCCIO2); also elsewhere on the board
CLK_EN: U5.B3 (PT3B/ULC_GPLLC_IN_A); also elsewhere on the board
FPGA_CLK33M: U5.A1 (PT3A/ULC_GPLLT_IN_A); also elsewhere on the board
FPGA_CSSPISN: U5.D2 (PL12A/CSSPISN); also elsewhere on the board
FPGA_DONE: U5.D3 (PL10B/DONE); also elsewhere on the board
FPGA_JTAG_TCK: U5.K14 (TCK); also elsewhere on the board
FPGA_JTAG_TDI: U5.L13 (TDI); also elsewhere on the board
FPGA_JTAG_TDO: U5.K13 (TDO); also elsewhere on the board
FPGA_JTAG_TMS: U5.L12 (TMS); also elsewhere on the board
FPGA_SOFT_RST#: U5.F1 (PL13A); also elsewhere on the board
FPGA_SPI_CLK: U5.G2 (PL14B/SO); also elsewhere on the board
FPGA_SPI_FLASH_CS#: U5.E3 (PL12B/CSSPIN); also elsewhere on the board
FPGA_SPI_MISO: U5.F3 (PL14A/CCLK); also elsewhere on the board
FPGA_SPI_MOSI: U5.H2 (PL15A/SI); also elsewhere on the board
FPGA_SPI_RTC_CS#: U5.B1 (PL2A/VREF1_7); also elsewhere on the board
FPGA_SPI_SD_CS#: U5.B2 (PL2B/VREF2_7); also elsewhere on the board
FPGA_TOE: R6.2, U5.K2 (TOE); also elsewhere on the board
FPGA_USER0: U5.G1 (PL13B); also elsewhere on the board
FPGA_USER1: U5.H1 (PL16A/PCLKT7_0); also elsewhere on the board
FPGA_USER2: U5.H3 (PL16B/PCLKC7_0); also elsewhere on the board
GB_CLK: U5.H13 (PR15A); also elsewhere on the board
GB_CS#: U5.G14 (PR13B); also elsewhere on the board
GB_RD#: U5.G13 (PR14B); also elsewhere on the board
GB_WR#: U5.H14 (PR16A/PCLKT2_0); also elsewhere on the board
GND: C20.2, C21.2, C22.2, C24.2, C25.2, C26.2, C29.2, C30.2, C33.2, C35.2, C36.2, U5.B4 (ULC_GNDPLL), U5.B8 (GNDIO0), U5.C1 (GNDIO7), U5.C6 (GNDIO0), U5.C13 (GNDIO2), U5.D1 (PL11A/CFG1), U5.E2 (GNDIO7), U5.E13 (GNDIO2), U5.J1 (GND), U5.K1 (CFG0), U5.M11 (LRC_GNDPLL); also elsewhere on the board
PS_PGOOD: U5.G3 (PL15B/INITN); also elsewhere on the board
RAM_A17: U5.E14 (PR11B); also elsewhere on the board
RAM_A18: U5.E12 (PR12A); also elsewhere on the board
RAM_A19: U5.F14 (PR13A); also elsewhere on the board
RAM_A21: U5.B14 (PR2B/VREF2_2); also elsewhere on the board
RAM_ADQ0: U5.A6 (PT15A); also elsewhere on the board
RAM_ADQ1: U5.A2 (PT2A/VREF1_0); also elsewhere on the board
RAM_ADQ2: U5.B6 (PT14A); also elsewhere on the board
RAM_ADQ3: U5.A7 (PT15B); also elsewhere on the board
RAM_ADQ5: U5.B9 (PT17B); also elsewhere on the board
RAM_ADQ6: U5.A10 (PT19B/PCLKC0_0); also elsewhere on the board
RAM_ADQ7: U5.A14 (PR2A/VREF1_2); also elsewhere on the board
RAM_ADQ8: U5.A5 (PT4B/ULC_GPLLC_FB_A); also elsewhere on the board
RAM_ADQ9: U5.C8 (PT16A); also elsewhere on the board
RAM_ADQ10: U5.A8 (PT17A); also elsewhere on the board
RAM_ADQ11: U5.A3 (PT2B/VREF2_0); also elsewhere on the board
RAM_ADQ12: U5.D14 (PR11A); also elsewhere on the board
RAM_ADQ13: U5.C10 (PT18B); also elsewhere on the board
RAM_ADQ14: U5.A9 (PT18A); also elsewhere on the board
RAM_ADV#: U5.C5 (PT4A/ULC_GPLLT_FB_A); also elsewhere on the board
RAM_CE0#: U5.D13 (PR10B); also elsewhere on the board
RAM_CE1#: U5.G12 (PR14A); also elsewhere on the board
RAM_CLK: U5.B10 (PT19A/PCLKT0_0); also elsewhere on the board
RAM_CRE: U5.F12 (PR12B); also elsewhere on the board
RAM_LB#: U5.H12 (PR15B); also elsewhere on the board
RAM_OE#: U5.C9 (PT16B); also elsewhere on the board
RAM_UB#: U5.J12 (PR16B/PCLKC2_0); also elsewhere on the board
RAM_WAIT: U5.C7 (PT14B); also elsewhere on the board
RAM_WE#: U5.D12 (PR10A); also elsewhere on the board
RTC_RST#: U5.E1 (PL11B); also elsewhere on the board

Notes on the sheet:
This sheet contains connections to the FPGA. It contains the following: - PSRAM connections - General purpose signals - SPI bus - Clocking - JTAG connections
Note about GB_* signals on 1V8 bank: These pins are only used as inputs. The sysIO datasheets states that 1V8 IO banks can still accept 3V3 input logic.

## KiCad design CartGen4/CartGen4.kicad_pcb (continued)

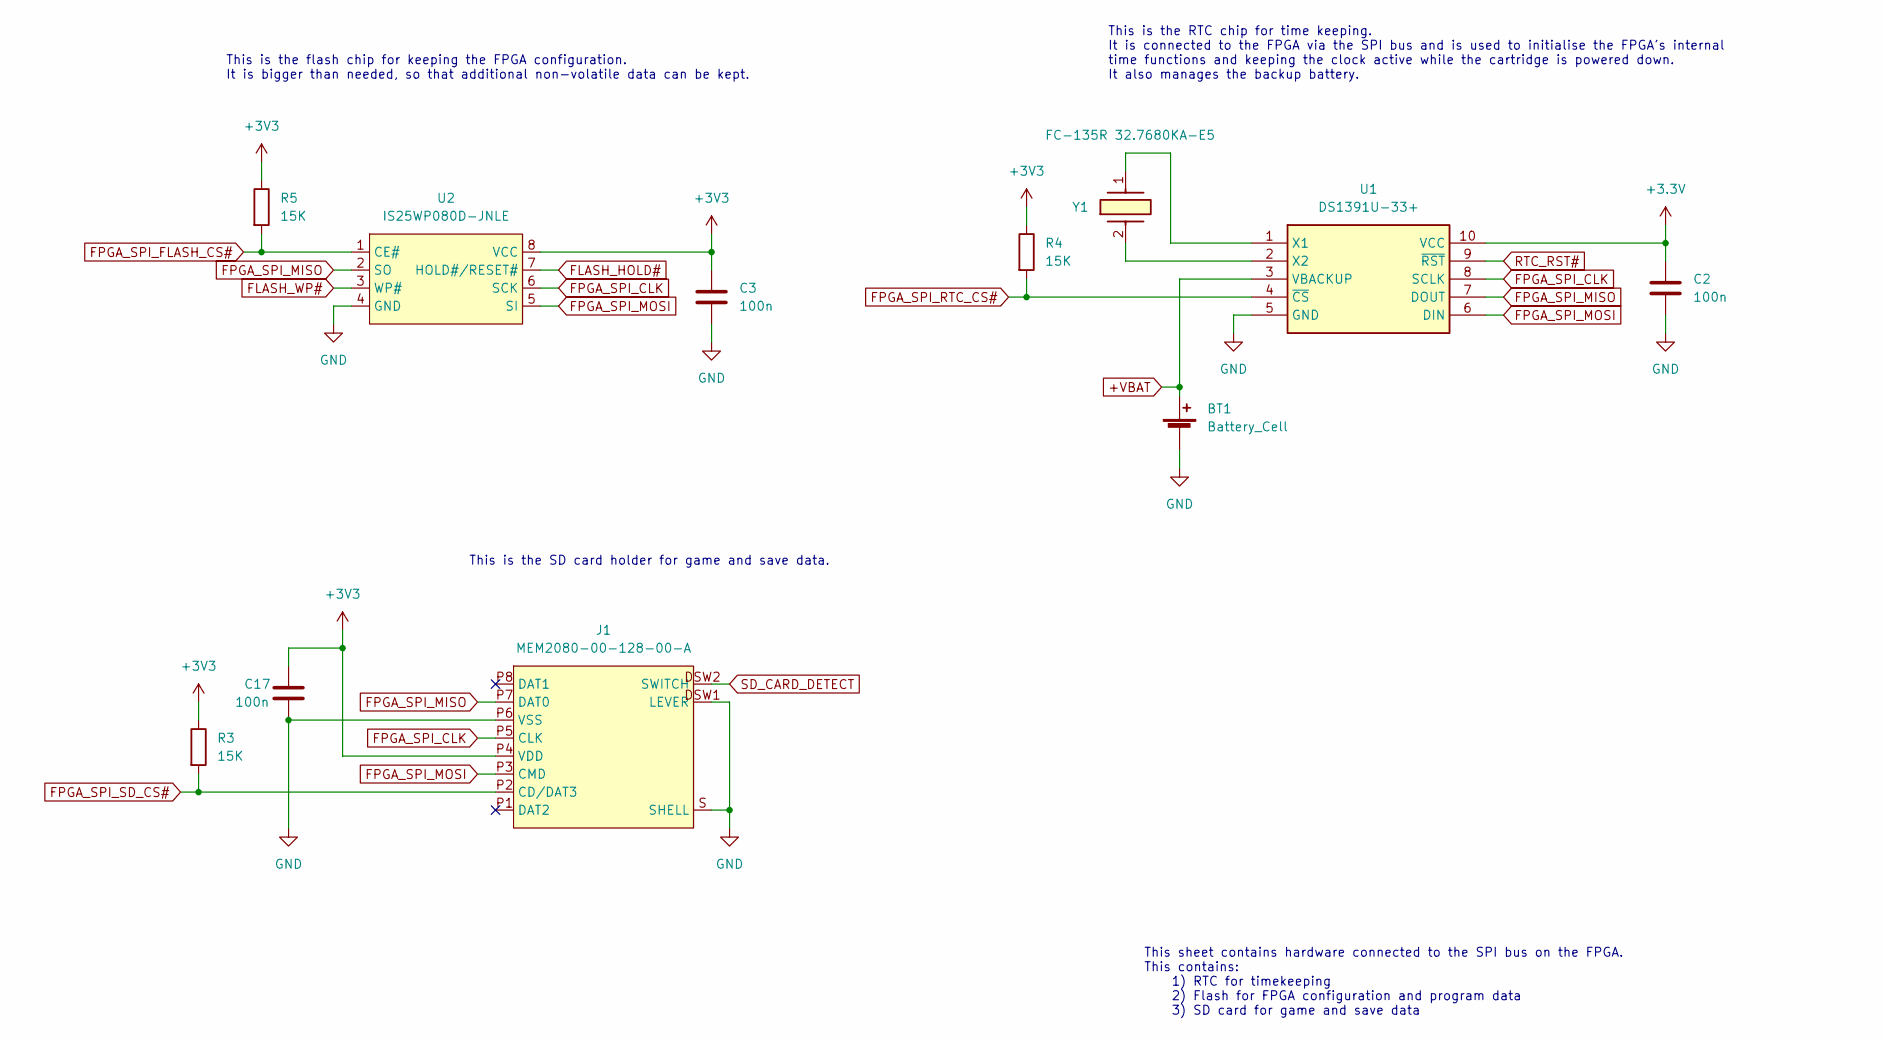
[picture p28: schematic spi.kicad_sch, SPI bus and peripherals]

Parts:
BT1: Battery_Cell; 2894
C2, C3, C17: 100n; C_0402_1005Metric_Pad0.74x0.62mm_HandSolder; Tolerance 20%; Voltage 3V3
J1: MEM2080-00-128-00-A
R3, R4, R5: 15K; R_0402_1005Metric_Pad0.72x0.64mm_HandSolder; Tolerance 10%
U1: DS1391U-33+; SOP50P490X110-10N
U2: IS25WP080D-JNLE; NE555DR
Y1: FC-135R 32.7680KA-E5; FC135R327680KAE3

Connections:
+VBAT: BT1.1 (+), U1.3 (VBACKUP)
FLASH_HOLD#: U2.7 (HOLD#/RESET#); also elsewhere on the board
FLASH_WP#: U2.3 (WP#); also elsewhere on the board
FPGA_SPI_CLK: J1.P5 (CLK), U1.8 (SCLK), U2.6 (SCK); also elsewhere on the board
FPGA_SPI_FLASH_CS#: R5.2, U2.1 (CE#); also elsewhere on the board
FPGA_SPI_MISO: J1.P7 (DAT0), U1.7 (DOUT), U2.2 (SO); also elsewhere on the board
FPGA_SPI_MOSI: J1.P3 (CMD), U1.6 (DIN), U2.5 (SI); also elsewhere on the board
FPGA_SPI_RTC_CS#: R4.2, U1.4 (~CS); also elsewhere on the board
FPGA_SPI_SD_CS#: J1.P2 (CD/DAT3), R3.2; also elsewhere on the board
GND: BT1.2 (-), C2.2, C3.2, C17.2, J1.DSW1 (LEVER), J1.P6 (VSS), J1.S (SHELL), U1.5 (GND), U2.4 (GND); also elsewhere on the board
unnamed: U1.1 (X1), Y1.1 (CRYSTAL)
unnamed: U1.2 (X2), Y1.2 (CRYSTAL)
RTC_RST#: U1.9 (~RST); also elsewhere on the board
SD_CARD_DETECT: J1.DSW2 (SWITCH); also elsewhere on the board

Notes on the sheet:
This is the RTC chip for time keeping. It is connected to the FPGA via the SPI bus and is used to initialise the FPGA's internal time functions and keeping the clock active while the cartridge is powered down. It also manages the backup battery.
This sheet contains hardware connected to the SPI bus on the FPGA. This contains: 1) RTC for timekeeping 2) Flash for FPGA configuration and program data 3) SD card for game and save data
This is the SD card holder for game and save data.
This is the flash chip for keeping the FPGA configuration. It is bigger than needed, so that additional non-volatile data can be kept.

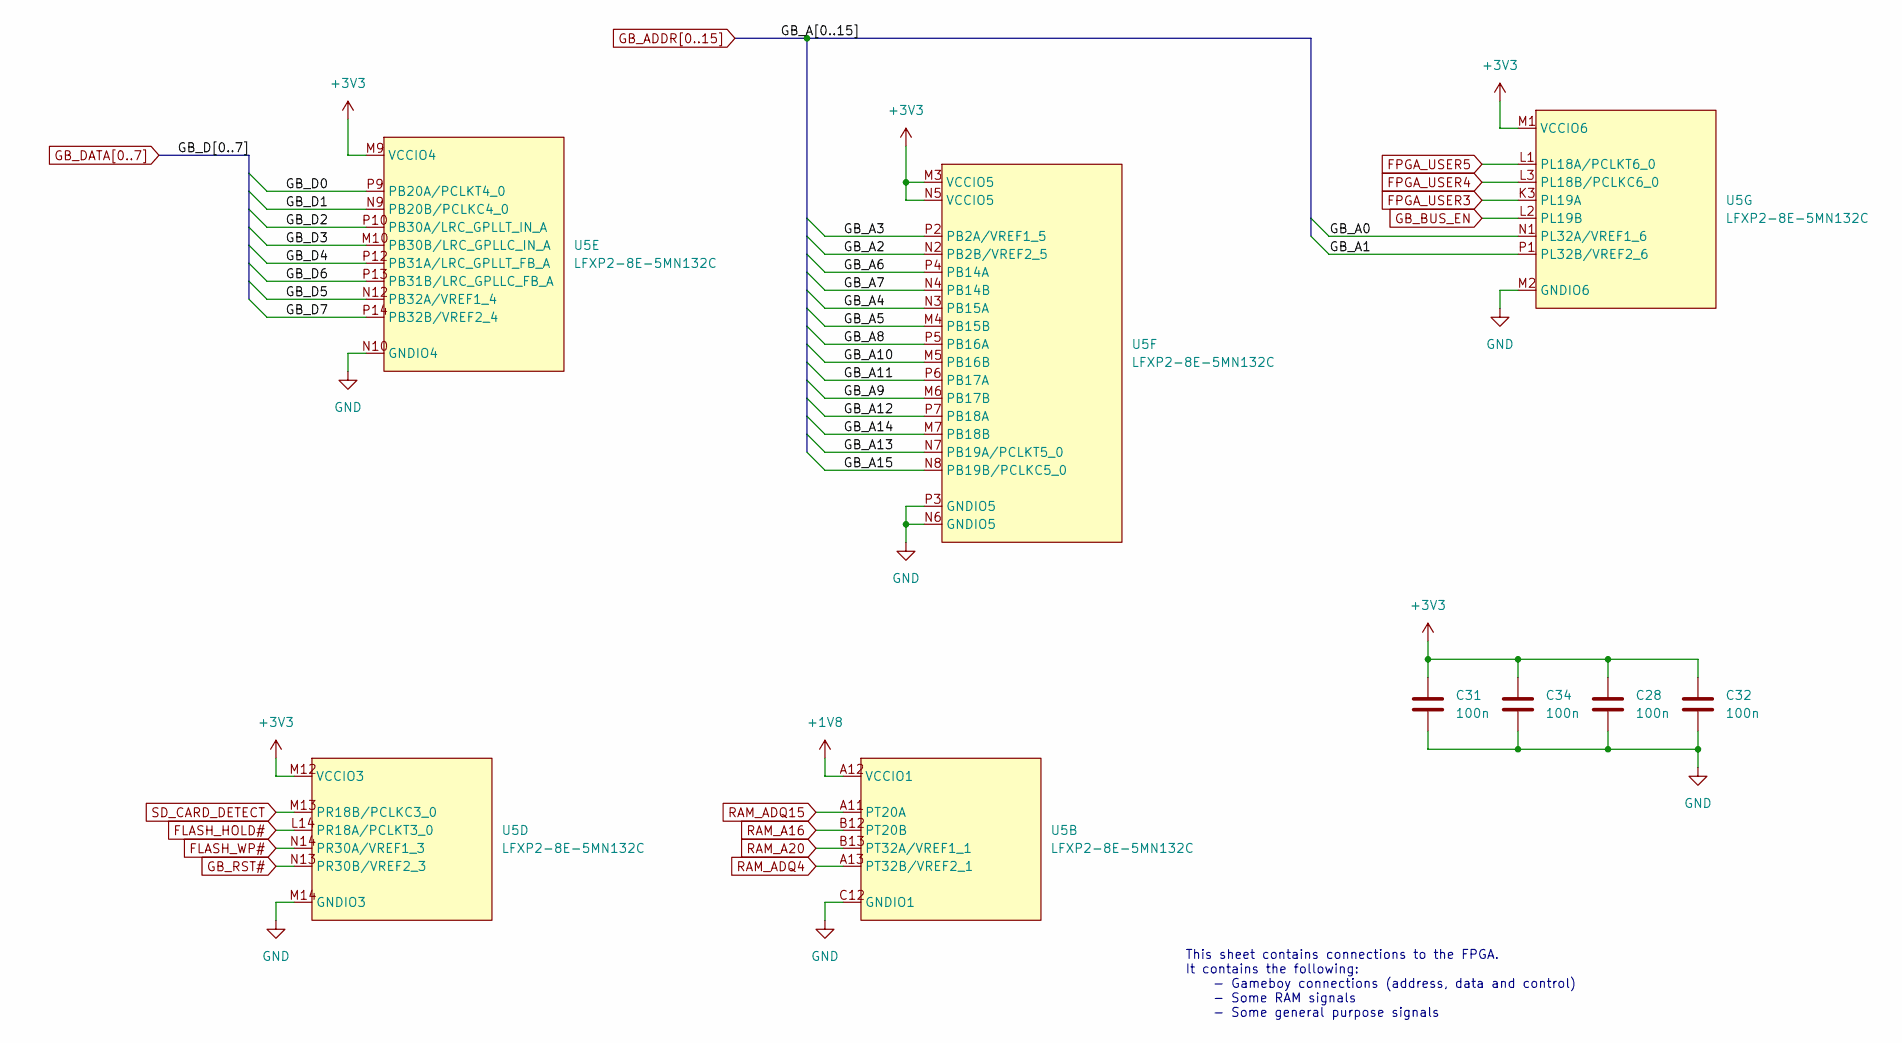
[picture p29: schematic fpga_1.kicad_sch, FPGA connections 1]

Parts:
C28, C31, C32, C34: 100n; C_0402_1005Metric_Pad0.74x0.62mm_HandSolder; Tolerance 20%; Voltage 3V3
U5: LFXP2-8E-5MN132C; BGA132C50P14X14_800X800X135

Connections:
+1V8: U5.A12 (VCCIO1); also elsewhere on the board
FLASH_HOLD#: U5.L14 (PR18A/PCLKT3_0); also elsewhere on the board
FLASH_WP#: U5.N14 (PR30A/VREF1_3); also elsewhere on the board
FPGA_USER3: U5.K3 (PL19A); also elsewhere on the board
FPGA_USER4: U5.L3 (PL18B/PCLKC6_0); also elsewhere on the board
FPGA_USER5: U5.L1 (PL18A/PCLKT6_0); also elsewhere on the board
GB_ADDR0: U5.N1 (PL32A/VREF1_6); also elsewhere on the board
GB_ADDR1: U5.P1 (PL32B/VREF2_6); also elsewhere on the board
GB_ADDR2: U5.N2 (PB2B/VREF2_5); also elsewhere on the board
GB_ADDR3: U5.P2 (PB2A/VREF1_5); also elsewhere on the board
GB_ADDR4: U5.N3 (PB15A); also elsewhere on the board
GB_ADDR5: U5.M4 (PB15B); also elsewhere on the board
GB_ADDR6: U5.P4 (PB14A); also elsewhere on the board
GB_ADDR7: U5.N4 (PB14B); also elsewhere on the board
GB_ADDR8: U5.P5 (PB16A); also elsewhere on the board
GB_ADDR9: U5.M6 (PB17B); also elsewhere on the board
GB_ADDR10: U5.M5 (PB16B); also elsewhere on the board
GB_ADDR11: U5.P6 (PB17A); also elsewhere on the board
GB_ADDR12: U5.P7 (PB18A); also elsewhere on the board
GB_ADDR13: U5.N7 (PB19A/PCLKT5_0); also elsewhere on the board
GB_ADDR14: U5.M7 (PB18B); also elsewhere on the board
GB_ADDR15: U5.N8 (PB19B/PCLKC5_0); also elsewhere on the board
GB_BUS_EN: U5.L2 (PL19B); also elsewhere on the board
GB_DATA0: U5.P9 (PB20A/PCLKT4_0); also elsewhere on the board
GB_DATA1: U5.N9 (PB20B/PCLKC4_0); also elsewhere on the board
GB_DATA2: U5.P10 (PB30A/LRC_GPLLT_IN_A); also elsewhere on the board
GB_DATA3: U5.M10 (PB30B/LRC_GPLLC_IN_A); also elsewhere on the board
GB_DATA4: U5.P12 (PB31A/LRC_GPLLT_FB_A); also elsewhere on the board
GB_DATA5: U5.N12 (PB32A/VREF1_4); also elsewhere on the board
GB_DATA6: U5.P13 (PB31B/LRC_GPLLC_FB_A); also elsewhere on the board
GB_DATA7: U5.P14 (PB32B/VREF2_4); also elsewhere on the board
GB_RST#: U5.N13 (PR30B/VREF2_3); also elsewhere on the board
GND: C28.2, C31.2, C32.2, C34.2, U5.C12 (GNDIO1), U5.M2 (GNDIO6), U5.M14 (GNDIO3), U5.N6 (GNDIO5), U5.N10 (GNDIO4), U5.P3 (GNDIO5); also elsewhere on the board
RAM_A16: U5.B12 (PT20B); also elsewhere on the board
RAM_A20: U5.B13 (PT32A/VREF1_1); also elsewhere on the board
RAM_ADQ4: U5.A13 (PT32B/VREF2_1); also elsewhere on the board
RAM_ADQ15: U5.A11 (PT20A); also elsewhere on the board
SD_CARD_DETECT: U5.M13 (PR18B/PCLKC3_0); also elsewhere on the board

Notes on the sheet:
This sheet contains connections to the FPGA. It contains the following: - Gameboy connections (address, data and control) - Some RAM signals - Some general purpose signals

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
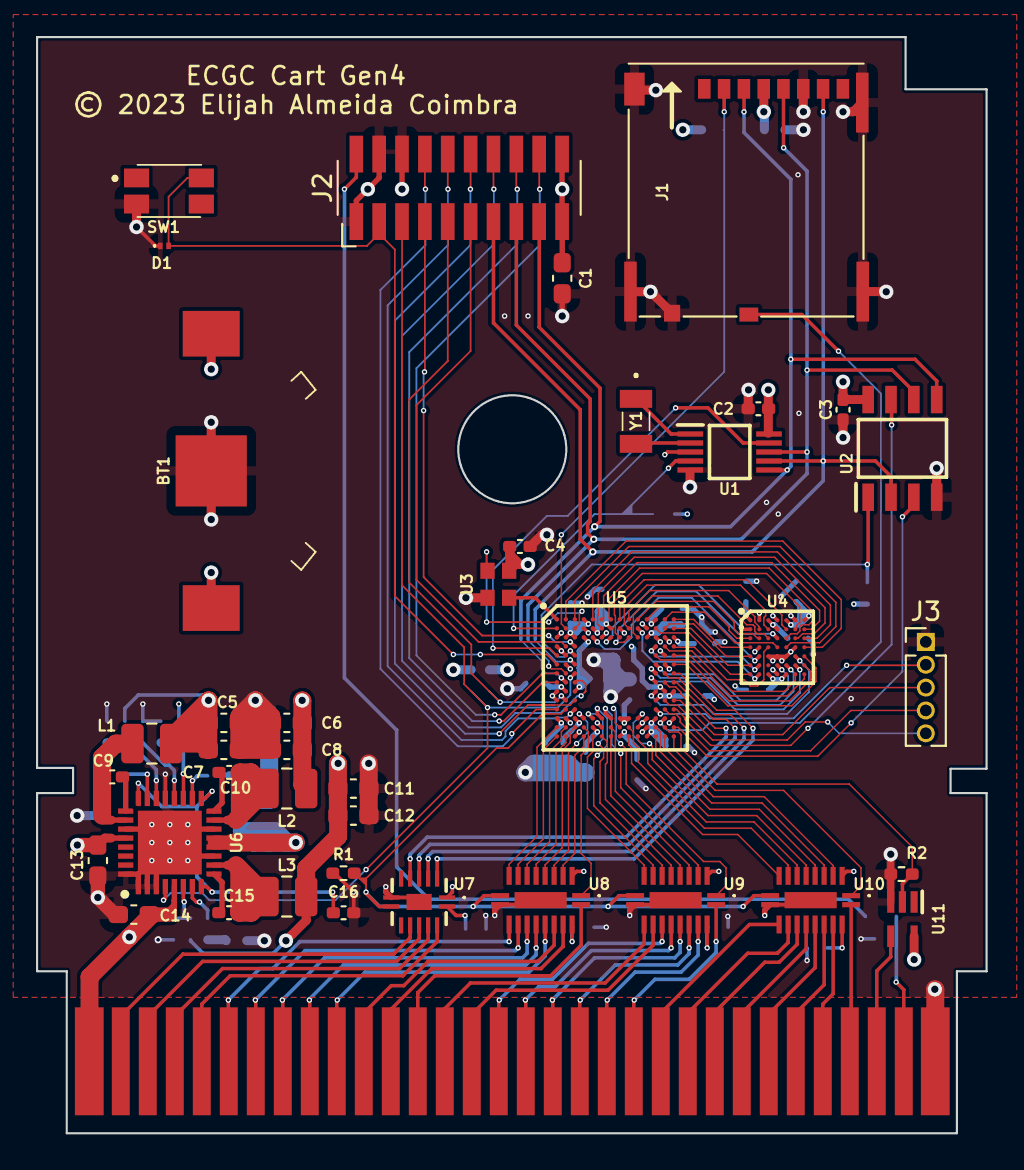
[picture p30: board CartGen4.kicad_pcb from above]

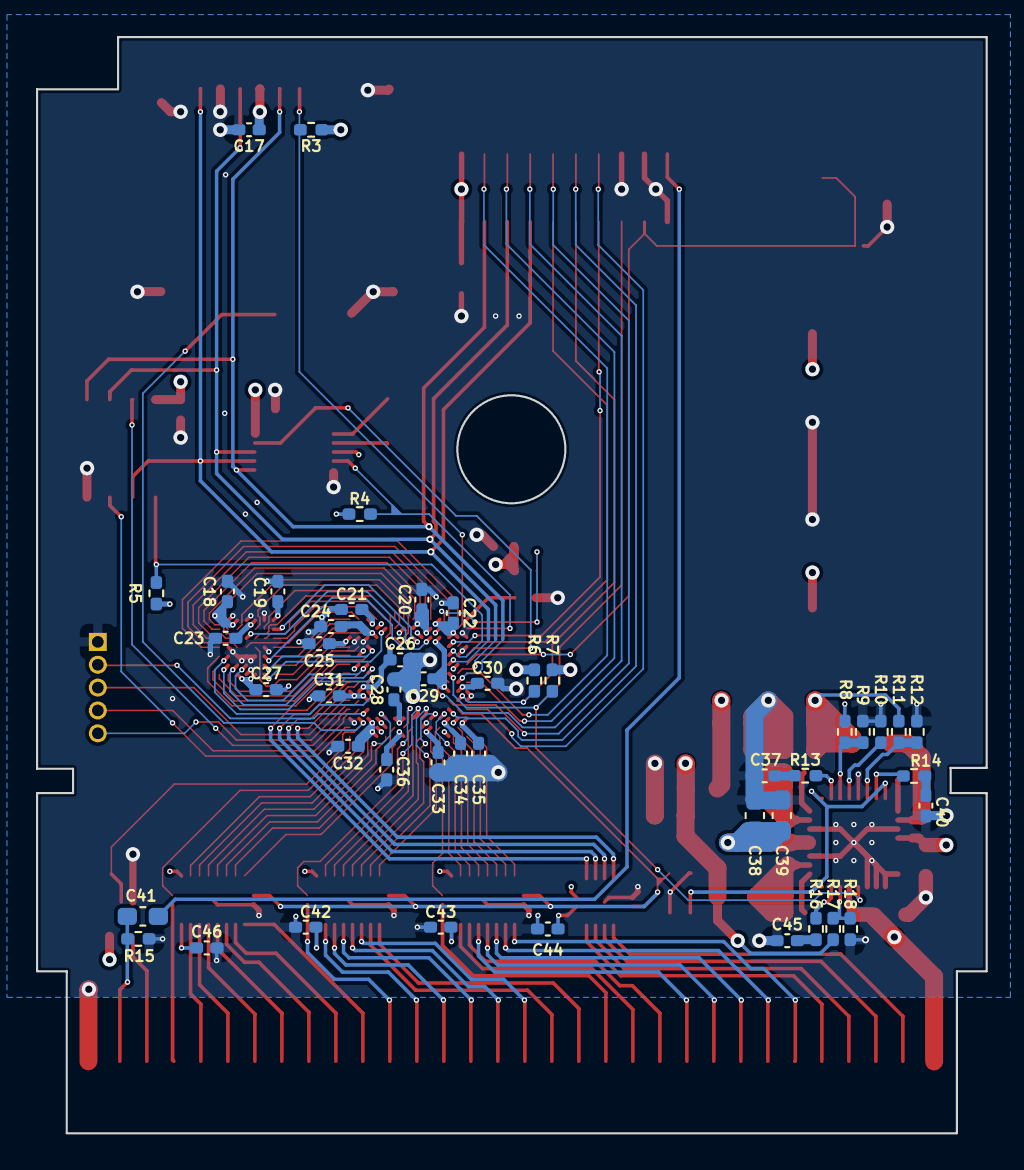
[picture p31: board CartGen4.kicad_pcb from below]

Board: 4 copper layers, 52.8 x 60.9 mm, 86 parts (46 on the bottom side), 145 nets.

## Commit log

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2023-03-02 Added bypass capacitors to prototype
    [CartGen3ProtoBoard.kicad_sch, bus-transceivers.kicad_sch, dram.kicad_sch]
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2023-09-22 Moved Gen3 to own directory
    [CartGen3.kicad_pcb, CartGen3.kicad_sch, CartGen3ProtoBoard.kicad_pcb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]
2023-09-22 Initial commit for Gen4
    [CartGen4.kicad_pcb, CartGen4.kicad_sch, bus-transceivers.kicad_sch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]
2023-09-22 Added FPGA and RAM symbols
    [CartGen4.kicad_sch, fpga.kicad_sch, gb_reset.kicad_sch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]
2023-09-27 Added RAM and clock
    [CartGen4.kicad_sch, fpga.kicad_sch, gb_reset_clock.kicad_sch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]
2023-09-27 Added RTC + Changed clock IC
    [CartGen4.kicad_sch, gb_reset_clock.kicad_sch]
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2023-10-02 Added SD card holder
    [CartGen4.kicad_sch, spi.kicad_sch]
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2023-10-03 Made part of FPGA connections
    [CartGen4.kicad_sch, fpga.kicad_sch, fpga_0.kicad_sch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]
2023-10-04 Added FPGA <> Gameboy connections
    [CartGen4.kicad_sch, fpga_1.kicad_sch]
2023-10-04 Connected and fixed reset
    [CartGen4.kicad_sch, fpga_0.kicad_sch, gb_reset_clock.kicad_sch]
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2023-10-04 Added reference designators to everything
    [CartGen4.kicad_sch, bus-transceivers.kicad_sch, fpga_0.kicad_sch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]
2023-10-04 Fixed DRC
    [CartGen4.kicad_sch, bus-transceivers.kicad_sch, fpga_0.kicad_sch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]
2023-10-04 Cleaned up symbol fields
    [bus-transceivers.kicad_sch, fpga_0.kicad_sch, gb_reset_clock.kicad_sch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]
2023-10-05 Added symbol information to obvious stuff
    [CartGen4.kicad_sch, bus-transceivers.kicad_sch, fpga_0.kicad_sch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]
2023-10-05 Added more symbol information
    [CartGen4.kicad_sch, bus-transceivers.kicad_sch, fpga_0.kicad_sch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]
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2023-10-05 Made and assigned clock footprint
    [CartGen4.kicad_sch, gb_reset_clock.kicad_sch]
2023-10-06 Assigned and made a few footprints
    [CartGen4.kicad_sch, bus-transceivers.kicad_sch, fpga_0.kicad_sch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]
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2023-10-06 Forgot to close footprint assignment tool
    [CartGen4.kicad_sch, bus-transceivers.kicad_sch, power_and_connectors.kicad_sch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]
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2023-10-08 Made general component placement + fixed ADDR
    [CartGen4.kicad_pcb, bus-transceivers.kicad_sch, fpga_0.kicad_sch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]
2023-10-08 Fixed PS_PGOOD pullup
    [CartGen4.kicad_pcb, CartGen4.kicad_sch, power_and_connectors.kicad_sch]
2023-10-08 Changed most R and C to 0402 size
    [CartGen4.kicad_pcb, CartGen4.kicad_sch, bus-transceivers.kicad_sch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]
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2023-10-09 Implemented feedback from colleague
    [CartGen4.kicad_pcb]
2023-10-09 Connected 5V side of level shifters
    [CartGen4.kicad_pcb]
2023-10-10 Configured proper clearance for XP2
    [CartGen4.kicad_pcb]
2023-10-10 Set same clearances on RAM
    [CartGen4.kicad_pcb]
2023-10-10 Wired bus transceivers power
    [CartGen4.kicad_pcb]
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2023-10-10 Updated to adhere to JLCPCB capabilities
    [CartGen4.kicad_pcb]
2023-10-10 Adjusted minimum via size
    [CartGen4.kicad_pcb]
2023-10-10 Updated to the latest JLCPCB capabilities
    [CartGen4.kicad_pcb]
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2023-10-13 Figured out how to run the DAMN ram traces
    [CartGen4.kicad_pcb]
2023-10-13 Started routing more ram, but I'd better sleep...
    [CartGen4.kicad_pcb, fpga_0.kicad_sch]
2023-10-17 More RAM wire changes (i wanna cry)
    [CartGen4.kicad_pcb, fpga_0.kicad_sch]
2023-10-17 Wired all RAM signal wires (finally...)
    [CartGen4.kicad_pcb, fpga_0.kicad_sch]
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2023-10-17 Added RAM decoupling capacitors
    [CartGen4.kicad_pcb]
2023-10-17 Connected FPGA ref clock
    [CartGen4.kicad_pcb]
2023-10-19 Wired FPGA decoupling caps
    [CartGen4.kicad_pcb]
2023-10-19 Planned rough location of SPI peripherals
    [CartGen4.kicad_pcb, spi.kicad_sch]
2023-10-19 Reviewed cartridge edge clearances
    [CartGen4.kicad_pcb]
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2023-10-21 Added missing SPI CS
    [CartGen4.kicad_sch, fpga_0.kicad_sch, fpga_1.kicad_sch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]
2023-10-21 Fanned out SPI bus
    [CartGen4.kicad_pcb]
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2023-10-24 Wired general purpose signals
    [CartGen4.kicad_pcb, CartGen4.kicad_sch, fpga_0.kicad_sch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]
2023-10-26 Wired 1V2 and 1V8 around FPGA and RAM
    [CartGen4.kicad_pcb, fpga_1.kicad_sch, gb_reset_clock.kicad_sch]
2023-10-26 Switched 1V2 and 1V8 supplies
    [CartGen4.kicad_pcb, CartGen4.kicad_sch, power_and_connectors.kicad_sch]
2023-10-26 Wired all voltage rails
    [CartGen4.kicad_pcb]
2023-10-27 Increased clearances between power planes
    [CartGen4.kicad_pcb]
2023-10-30 Change JTAG pins to 1mm pitch
    [CartGen4.kicad_pcb, CartGen4.kicad_sch, power_and_connectors.kicad_sch]
2023-10-31 Rerouted some RAM and GB CTRL traces
    [CartGen4.kicad_pcb, CartGen4.kicad_sch, fpga_0.kicad_sch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]
2023-10-31 Added external test header to schematic
    [CartGen4.kicad_sch, fpga_0.kicad_sch, fpga_1.kicad_sch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]
2023-10-31 Added power source to J3 header
    [CartGen4.kicad_sch, power_and_connectors.kicad_sch]
2023-10-31 Added J3 to PCB
    [CartGen4.kicad_pcb, CartGen4.kicad_sch, power_and_connectors.kicad_sch]
2023-10-31 Flipped J2 to make pin 1 GND
    [CartGen4.kicad_pcb, power_and_connectors.kicad_sch]
2023-10-31 Added GB_AUDIO to expansion port
    [CartGen4.kicad_pcb, CartGen4.kicad_sch, debug_ports.kicad_sch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]
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2023-10-31 Switched from 1.00mm to 1.27mm pin headers
    [CartGen4.kicad_pcb, CartGen4.kicad_sch, debug_ports.kicad_sch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]
2023-11-01 Changed J3 to SMD header
    [CartGen4.kicad_pcb, CartGen4.kicad_sch, debug_ports.kicad_sch]
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2023-11-02 Increased clearances between GB lines
    [CartGen4.kicad_pcb]
2023-11-02 Added bypass capacitors to transceivers
    [CartGen4.kicad_pcb, CartGen4.kicad_sch, bus-transceivers.kicad_sch]
2023-11-02 Routed almost forgotten GB_BUS_EN
    [CartGen4.kicad_pcb, CartGen4.kicad_sch, bus-transceivers.kicad_sch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]
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2023-11-02 Fixed clearance violations on power plane
    [CartGen4.kicad_pcb]
2023-11-06 Changed GB_AUDIO location for better noise isolation
    [CartGen4.kicad_pcb, debug_ports.kicad_sch]
2023-11-06 Changed power pins to give the 3V3 rail 3A capabilities
    [CartGen4.kicad_pcb, CartGen4.kicad_sch, power_and_connectors.kicad_sch]
2023-11-06 Added decoupling cap to expansion header to be sure
    [CartGen4.kicad_pcb, CartGen4.kicad_sch, debug_ports.kicad_sch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]
2023-11-07 Fixed GB_BUS_EN not being on 3V3 bank Added CLK_EN to ext clock
    [CartGen4.kicad_pcb, CartGen4.kicad_sch, debug_ports.kicad_sch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]
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2023-11-17 Fixed U10 excluded from F.Paste and F.Mask
    [CartGen4-B_Cu.gbr, CartGen4-B_Mask.gbr, CartGen4-B_Paste.gbr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]
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2023-11-17 Changed 50K size to 0603 due to unavailability
    [CartGen4.kicad_pcb, CartGen4.kicad_sch, bus-transceivers.kicad_sch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]
2023-11-17 Revert "Changed 50K size to 0603 due to unavailability"
    This reverts commit 7b462f06fc85ccc42ac1f7842e04da7b6c33922f.
    [CartGen4.kicad_pcb, CartGen4.kicad_sch, bus-transceivers.kicad_sch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]
2023-11-17 Added missing recommendations
    [CartGen4.kicad_sch, bus-transceivers.kicad_sch, fpga_0.kicad_sch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]
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2023-11-20 Minor fixes to reference designators
    [CartGen4.kicad_pcb, debug_ports.kicad_sch]
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2024-01-09 Fixed silk screen placement Fixed RD misplacement Changed R16 supplier suggestion
    [CartGen4.kicad_pcb, gb_reset_clock.kicad_sch, power_and_connectors.kicad_sch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]
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2024-02-25 Added improvement notes for documenting problems with current gen

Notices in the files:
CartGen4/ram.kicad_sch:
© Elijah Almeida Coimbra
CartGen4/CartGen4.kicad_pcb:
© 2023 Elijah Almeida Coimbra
